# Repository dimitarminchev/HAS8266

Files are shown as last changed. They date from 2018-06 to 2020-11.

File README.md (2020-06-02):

# HAS & LAS 8266
Internet of Things (IoT) Home Automation System (HAS) and  Laboratory Automation System (LAS) based on ESP8266 with Energy Measurement Capabilities (HLW8012).

### Information
The basic hardware components are the ESP8266 micro-controller by Espressif and energy meter chip HLW8012 by HLW Technology. The Software works over the TCP/IP stack and uses the MQTT protocol to communicate between the devices. The minimum configuration of the platform includes one control device called Gateway and two or more manageable Host devices. The user friendly, simplified interface is web based. The platform has open software and hardware. 

### Authors
- Software: Dimitar Minchev, PhD of Informatics,  e-mail: <mitko@bfu.bg>
- Hardware: Atanas Dimitrov, PhD of Robots and manipulators, e-mail: <atanas@bfu.bg>

### Hardware and Software
The project is published as Open Source Hardware and Software.

Open Hardware
Open Source

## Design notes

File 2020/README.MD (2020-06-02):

# LAS8266
Internet of Things (IoT) Laboratory Automation System (LAS) based on ESP8266 with Energy Measurement Capabilities.

### Information
The basic hardware components are the ESP8266 micro-controller by Espressif and energy meter chip HLW8012 by HLW Technology. The Software works over the TCP/IP stack and uses the MQTT protocol to communicate between the devices. The minimum configuration of the LAS includes one control device called Gateway and two or more manageable Host devices. The user friendly, simplified interface is web based. The platform has open software and hardware. 

### Authors
- Software: Dimitar Minchev, PhD of Informatics,  e-mail: <mitko@bfu.bg>
- Hardware: Atanas Dimitrov, PhD of Robots and manipulators, e-mail: <atanas@bfu.bg>

### Youtube Demo
LAS8266 (https://youtu.be/b3r9DmQJEUk)

### Hardware


### Software
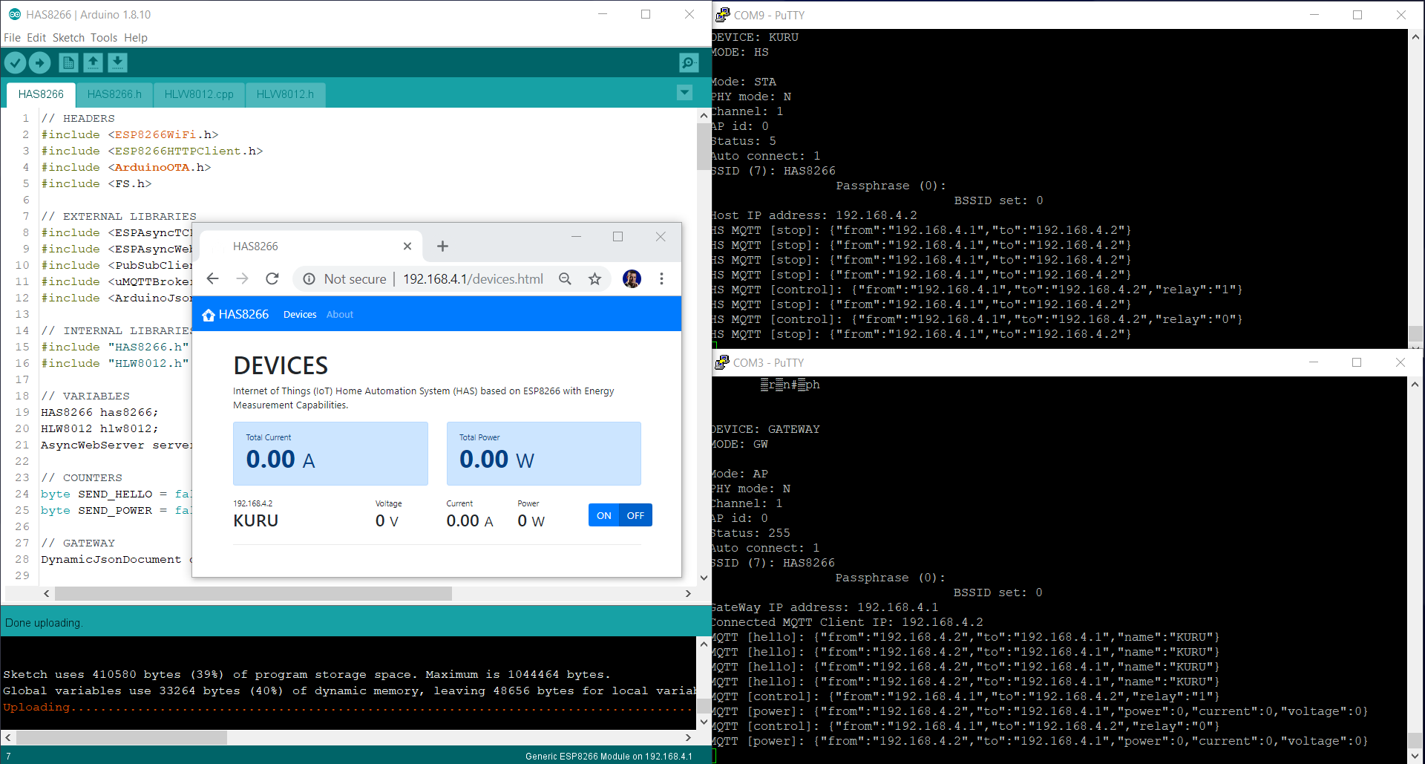
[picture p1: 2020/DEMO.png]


# Arduino 
### Libraries
- [ESPAsyncTCP](https://github.com/me-no-dev/ESPAsyncTCP)
- [ESPAsyncWebServer](https://github.com/me-no-dev/ESPAsyncWebServer)
- [PubSubClient](https://github.com/knolleary/pubsubclient)
- [uMQTTBroker](https://github.com/martin-ger/uMQTTBroker)
- [ArduinoJson](https://github.com/bblanchon/ArduinoJson)

### Settings
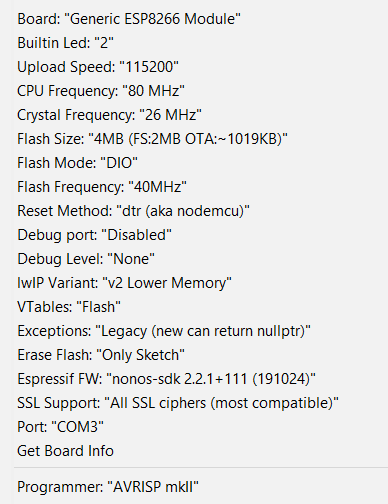
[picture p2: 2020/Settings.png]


The project is published as Open Source Hardware and Software.

Open Hardware
Open Source

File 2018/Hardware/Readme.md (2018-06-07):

# Hardware
In this directory you will find all gerber files needed for manufacturing the pcb of the HAS8266.

## HAS8266 Schematic
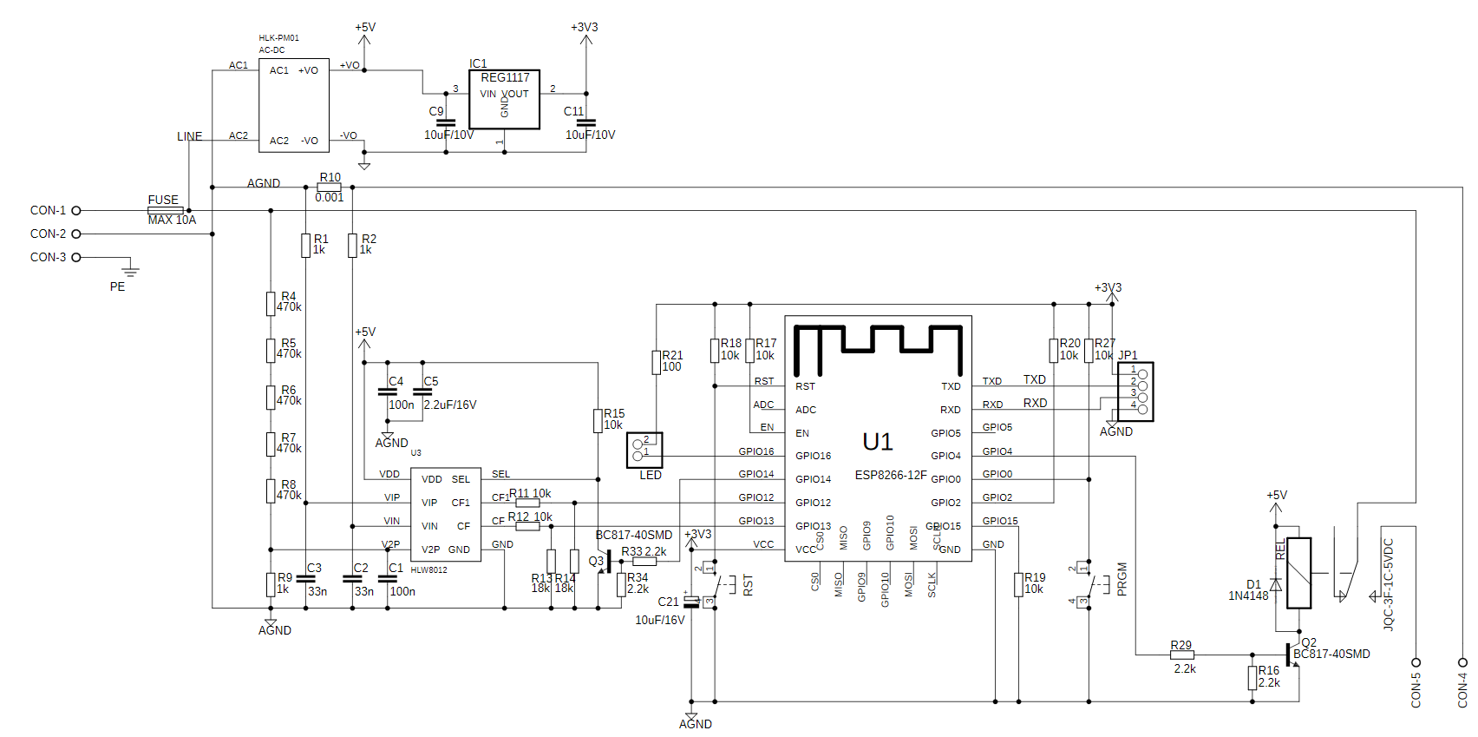
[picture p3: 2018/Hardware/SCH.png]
HAS8266 Schematic


## Gerber Files
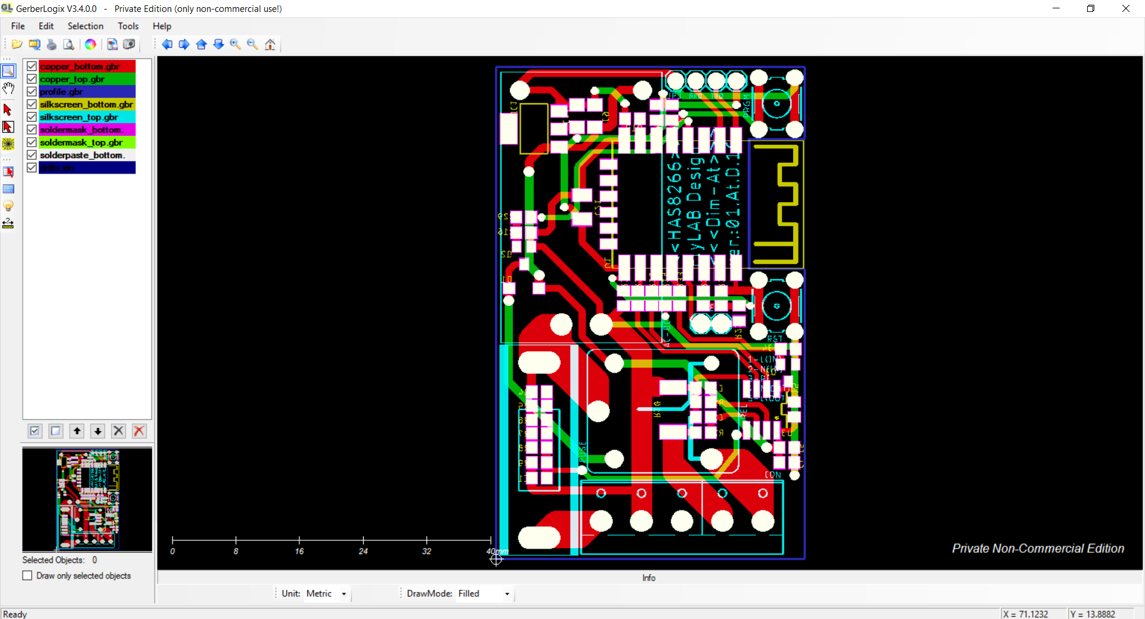
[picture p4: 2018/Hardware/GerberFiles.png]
Gerber Files


## Software
For design of PCB we used Autodesk Eagle
https://www.autodesk.com/products/eagle/free-download

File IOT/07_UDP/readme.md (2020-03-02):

# UDP
- ESP8266 Arduino Core UDP Demo
https://arduino-esp8266.readthedocs.io/en/latest/esp8266wifi/udp-examples.html

- UDP Demo GitHub Repository
https://github.com/esp8266/Arduino/blob/master/doc/esp8266wifi/udp-examples.rst

### Arduino
```
#include <ESP8266WiFi.h>
#include <WiFiUdp.h>

WiFiUDP Udp;

unsigned int localUdpPort = 5000; // local port to listen on
char incomingPacket[255]; // buffer for incoming packets
char replyPacket[] = "Thank You"; // a reply string to send back

void setup()
{
  Serial.begin(115200);
  Serial.println();

  // Access Point
  Serial.println("Access point waiting for client connection.");
  WiFi.mode(WIFI_AP);
  while (WiFi.softAPgetStationNum()== 0)
  {
    delay(1000);
    Serial.print(".");
  }
  
  // Udp
  Udp.begin(localUdpPort);
  Serial.println();
  Serial.printf("Now listening for packets at IP %s, UDP port %d\n", WiFi.softAPIP().toString().c_str(), localUdpPort);
}

void loop()
{
  delay(1000);
  int packetSize = Udp.parsePacket();
  if (packetSize)
  {
    // Receive incoming UDP packets
    Serial.printf("Received %d bytes from %s, port %d\n", packetSize, Udp.remoteIP().toString().c_str(), Udp.remotePort());
    int len = Udp.read(incomingPacket, 255);
    if (len > 0)
    {
      incomingPacket[len] = 0;
    }
    Serial.printf("UDP packet contents: %s\n", incomingPacket);

    // Send back a reply, to the IP address and port we got the packet from
    Udp.beginPacket(Udp.remoteIP(), Udp.remotePort());
    Udp.write(replyPacket);
    Udp.endPacket();
  }
}
```
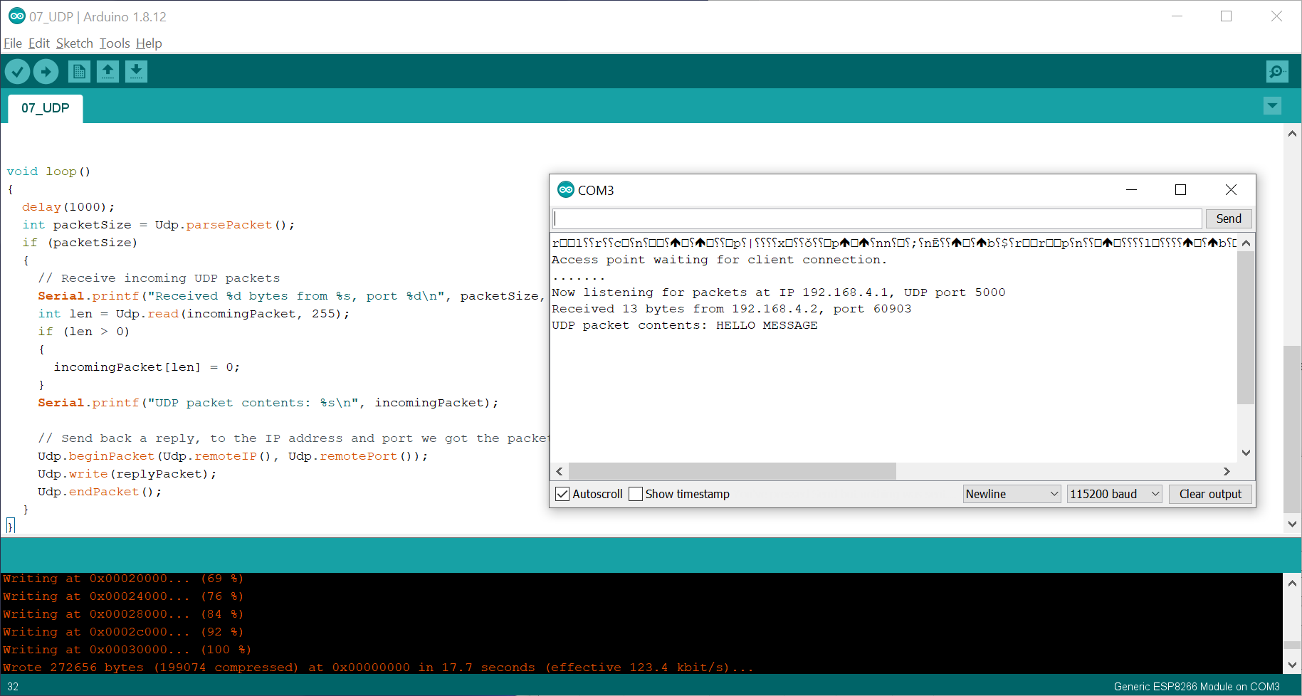
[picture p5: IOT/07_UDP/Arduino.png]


### Packet Sender
Packet Sender
https://packetsender.com/

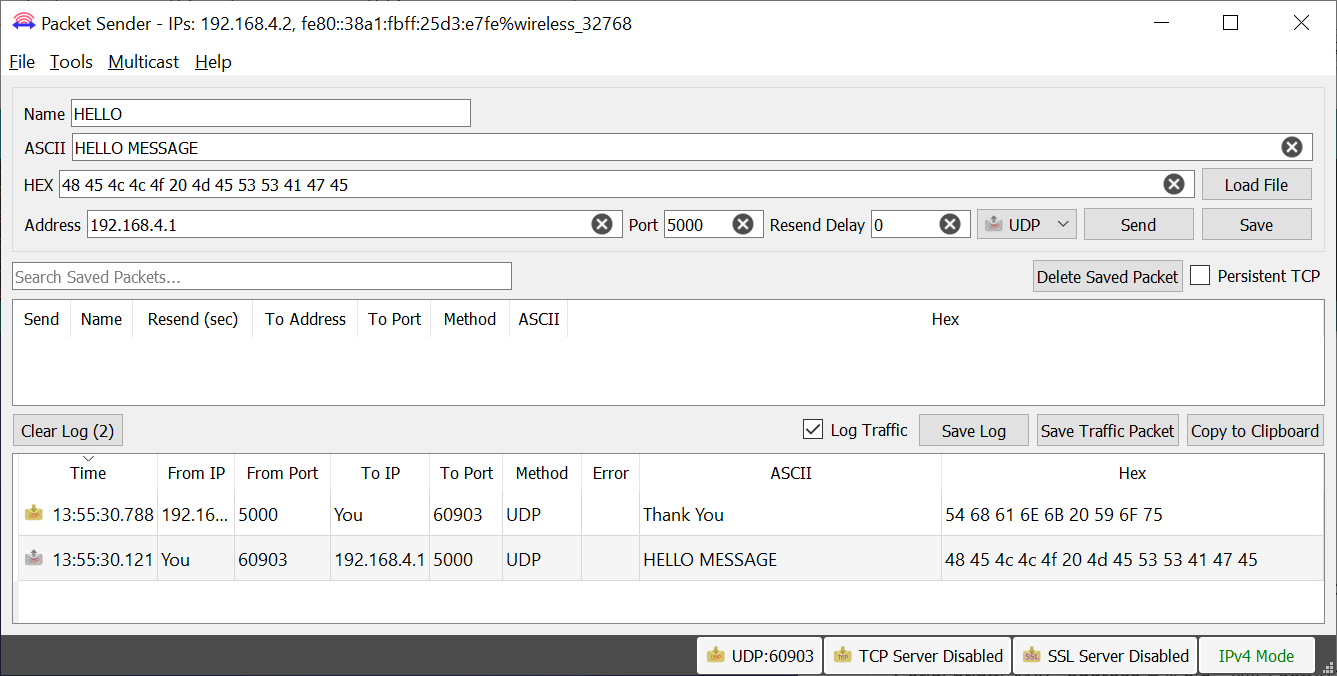
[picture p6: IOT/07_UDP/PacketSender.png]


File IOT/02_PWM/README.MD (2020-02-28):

# PWM
Arduino Pulse Width Modulation:
https://www.arduino.cc/en/Tutorial/PWM

```
// Initializing LED Pin
int led_pin = 16;

void setup() {
  //Declaring LED pin as output
  pinMode(led_pin, OUTPUT);
}

void loop() {
  // Fade In
  for(int i=0; i<255; i++){
    analogWrite(led_pin, i);
    delay(10);
  }
  // Fade Out
  for(int i=255; i>0; i--){
    analogWrite(led_pin, i);
    delay(10);
  }
}
```
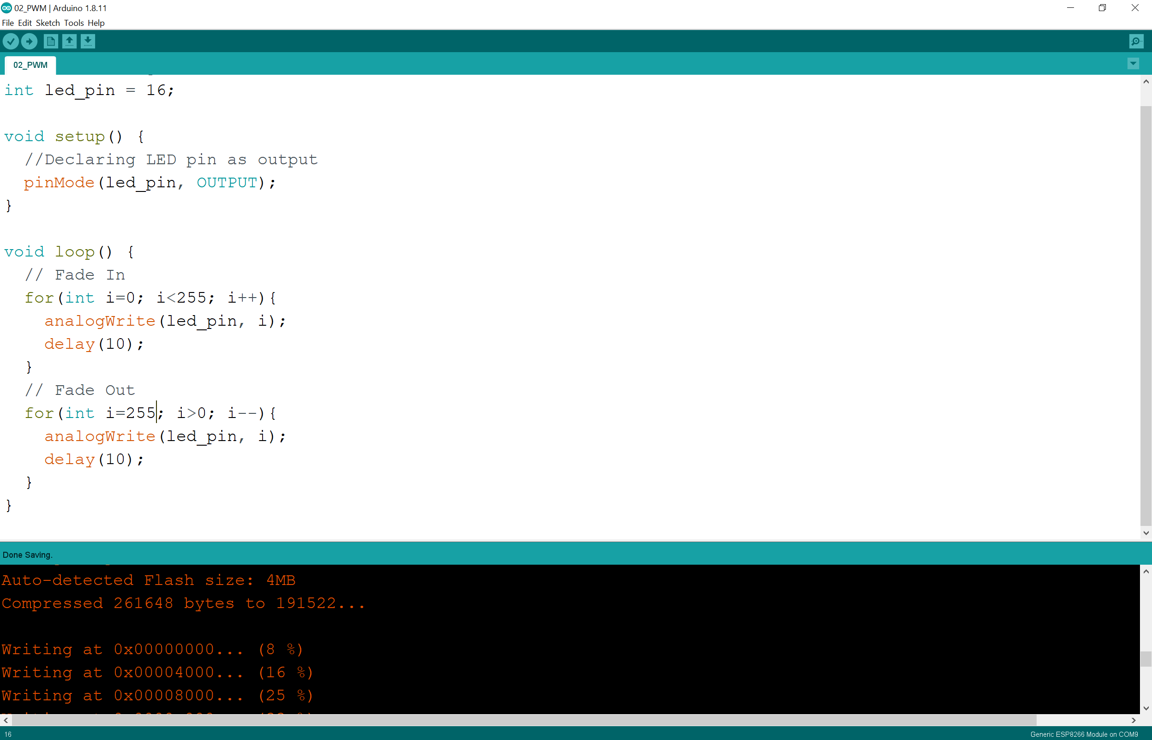
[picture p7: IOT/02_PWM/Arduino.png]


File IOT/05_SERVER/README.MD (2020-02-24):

# Access Point and Web Server
Start ESP8266 as a Access Point and then serve Client requests as a Web Server.

### Arduino
```
#include <ESP8266WiFi.h>
#include <ESP8266WebServer.h>
#include <FS.h>

// ESP8266 Web Server
ESP8266WebServer server(80);

// Setup
void setup(void) 
{
  // Access Point
  WiFi.mode(WIFI_AP);
  WiFi.softAP("ESP8266");
  // Server
  server.on("/", handleRequest);
  server.begin();
}

// Handle Client Request
void handleRequest() 
{
  // File System
  SPIFFS.begin();
  File file = SPIFFS.open("/index.html", "r");
  server.send(200, "text/html", file.readString());
  file.close();
  // server.send(200, "text/plain", "Hello world");
}

// Loop
void loop(void) 
{
  server.handleClient();
}
```
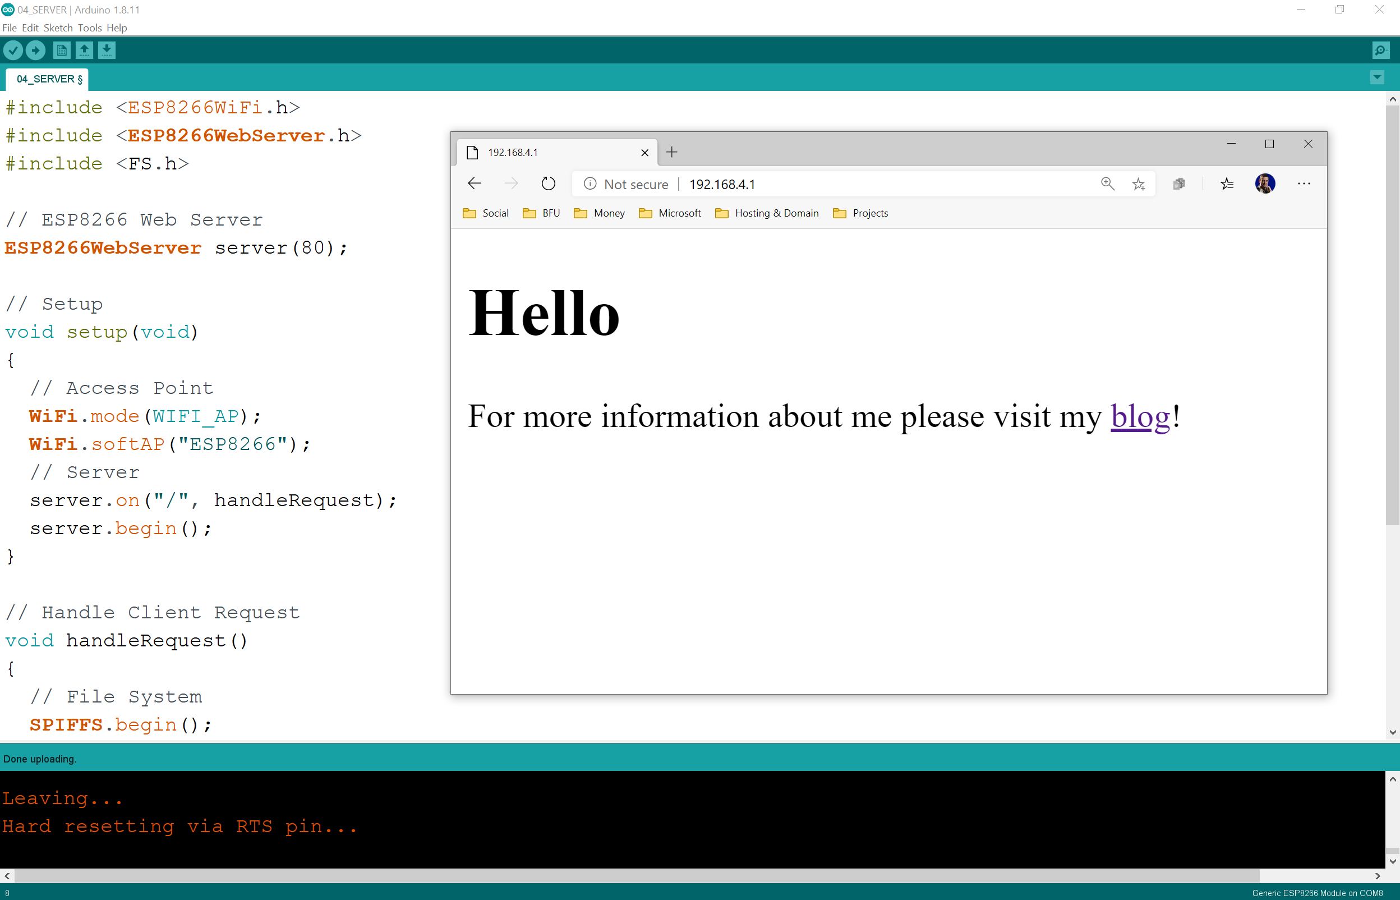
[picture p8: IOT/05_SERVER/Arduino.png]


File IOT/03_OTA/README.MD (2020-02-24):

# OTA

## Arduino
```
// Headers
#include <ESP8266WiFi.h>
#include <ESP8266mDNS.h>
#include <WiFiUdp.h>
#include <ArduinoOTA.h>

// WiFi Settings
#define SSID   "IBA_L@B"
#define PASS   ""

// Setup
void setup() 
{  
    // Connect to Wireless Network
    WiFi.mode(WIFI_STA);
    WiFi.begin(SSID,PASS);
    while (WiFi.status() != WL_CONNECTED) delay(1000);

    // OTA Updates 
    ArduinoOTA.setPort(8266); 
    ArduinoOTA.begin();
}

// Loop
void loop() 
{
    // Handle OTA Updates
    ArduinoOTA.handle();
}
```
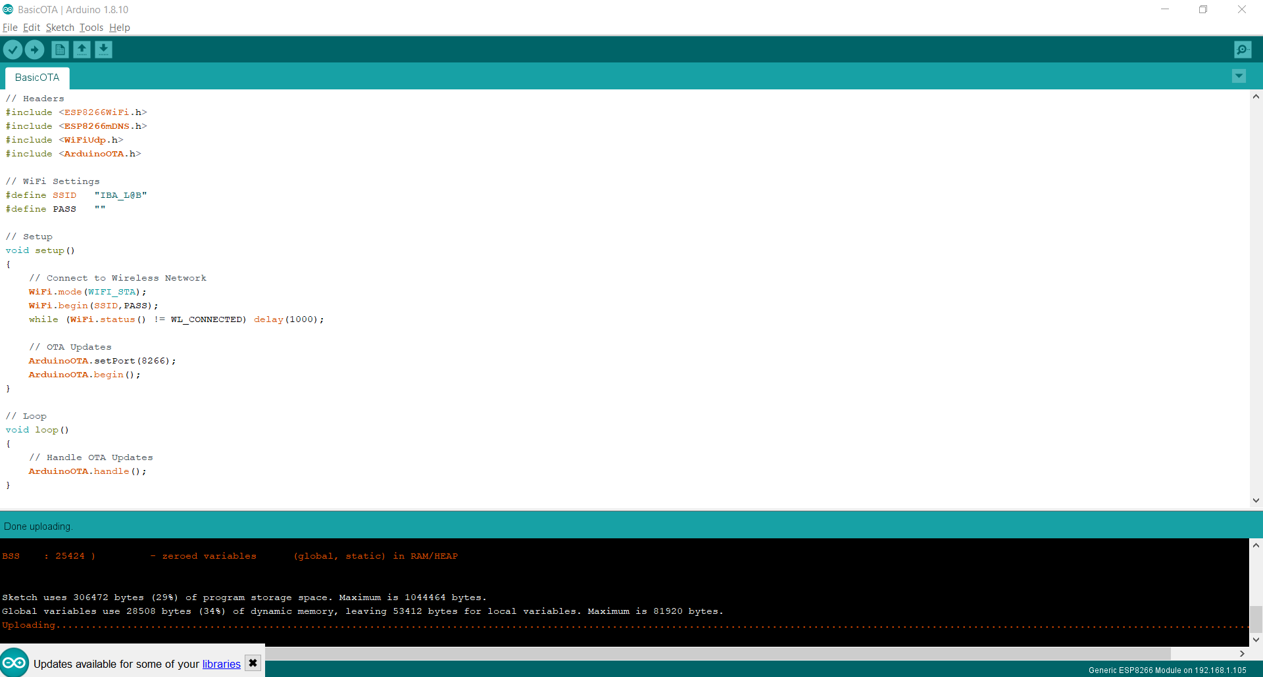
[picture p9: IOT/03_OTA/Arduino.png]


## PlatformIO
**platformio.ini**
```
; PlatformIO Project Configuration File

# ESP 8266 
[env:esp12e]
platform = espressif8266
board = esp12e
framework = arduino

# OTA 
upload_port = 192.168.1.105
upload_protocol = espota

# SERIAL 
; upload_port = COM3
; upload_speed = 115200
; monitor_speed = 115200
```
**main.cpp**
```
// Headers
#include <Arduino.h>
#include <ESP8266WiFi.h>
#include <WiFiUdp.h>
#include <ArduinoOTA.h>

// WiFi Settings
#define SSID   "IBA_L@B"
#define PASS   ""

// Setup
void setup() 
{  
    // Connect to Wireless Network
    WiFi.mode(WIFI_STA);
    WiFi.begin(SSID,PASS);
    while (WiFi.status() != WL_CONNECTED) delay(1000);

    // OTA Updates 
    ArduinoOTA.setPort(8266); 
    ArduinoOTA.begin();
}

// Loop
void loop() 
{
    // Handle OTA Updates
    ArduinoOTA.handle();
}
```
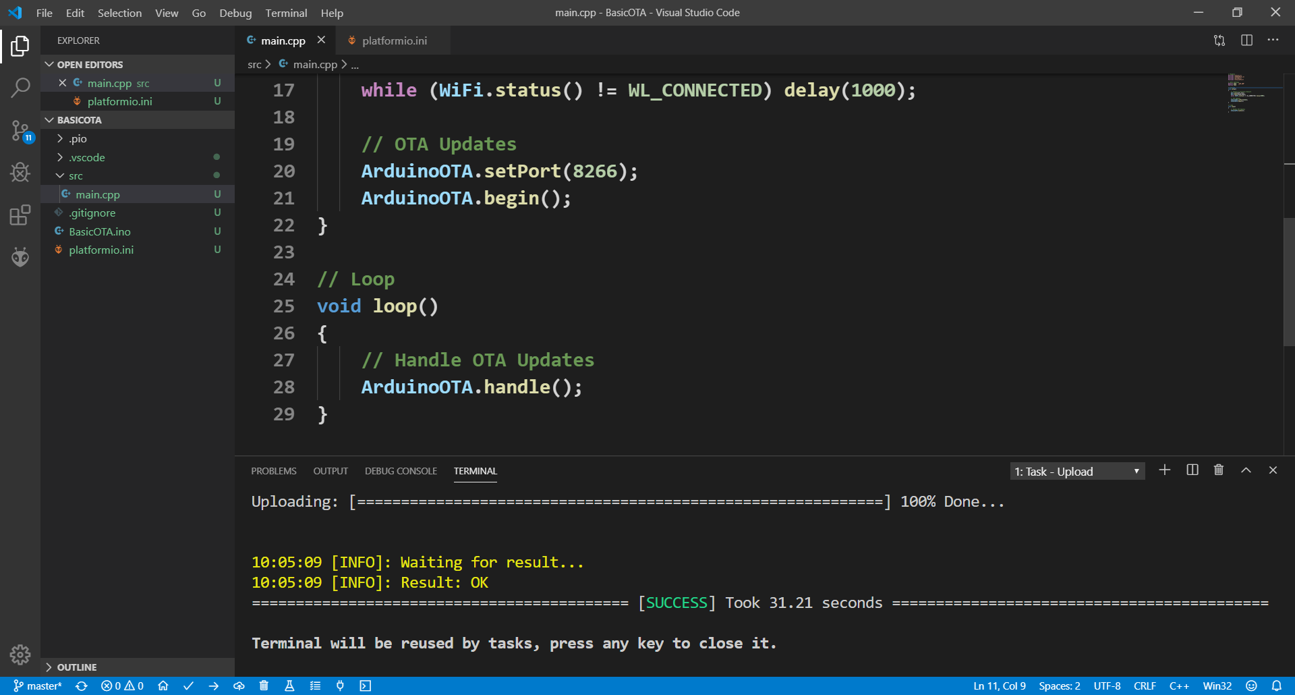
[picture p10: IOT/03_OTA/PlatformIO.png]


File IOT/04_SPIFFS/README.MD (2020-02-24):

# SPIFFS
- [SPIFFS](https://arduino-esp8266.readthedocs.io/en/latest/filesystem.html#flash-layout)
- [Arduino ESP8266 FileSystem Uploader](https://github.com/esp8266/arduino-esp8266fs-plugin/releases)
- [Python](https://go.microsoft.com/fwlink?linkID=2082640) 

### Arduino
```
// Headers
#include "FS.h"

// Setup
void setup() 
{
  Serial.begin(115200);
  
  // SPIFS
  SPIFFS.begin();
  Dir dir = SPIFFS.openDir("/");
  while (dir.next()) 
  {
    Serial.print(dir.fileName());
    if(dir.fileSize()) 
    {
        File f = dir.openFile("r");
        Serial.println(f.size());
    }
  }
}

// Loop
void loop() 
{
  // nope
}
```
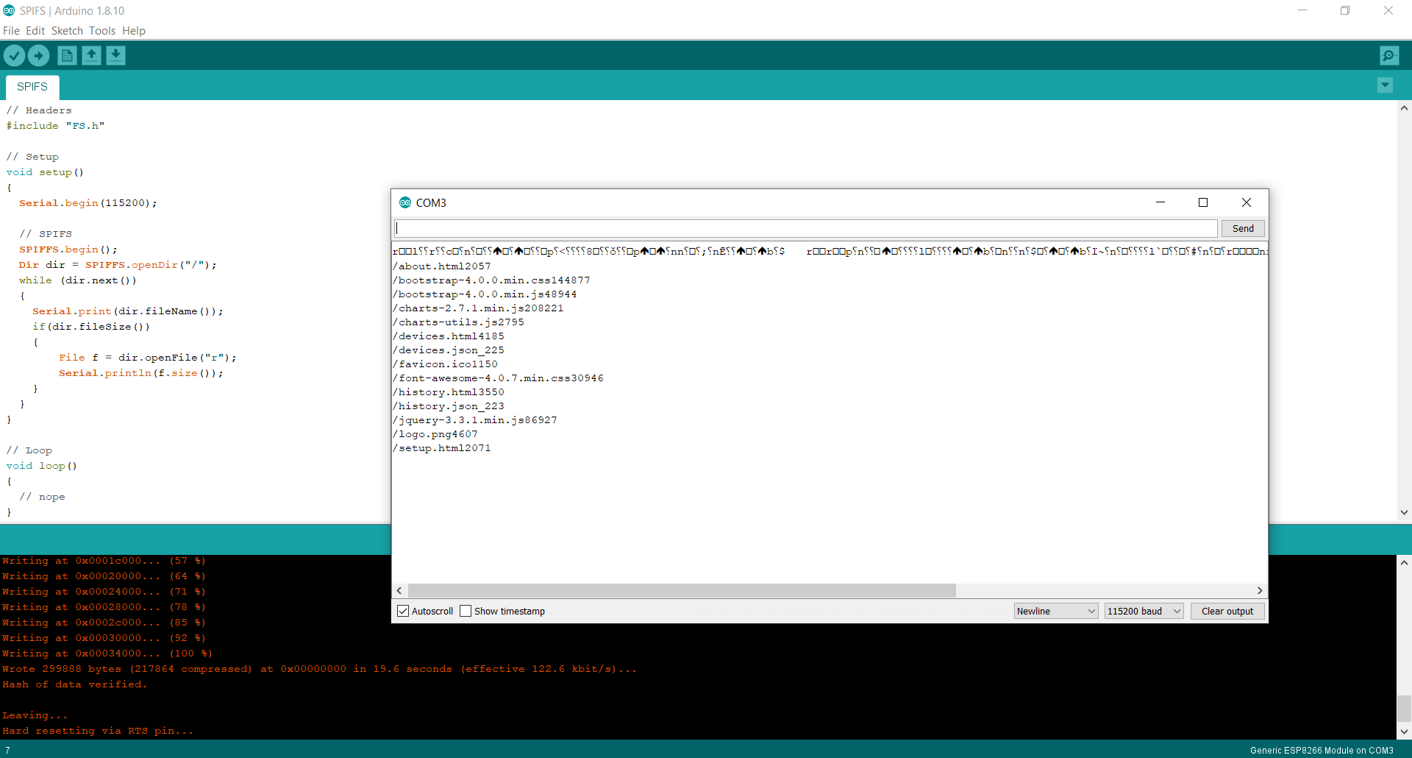
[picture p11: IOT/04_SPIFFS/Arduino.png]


## PlatformIO
**platformio.ini**
```
; PlatformIO Project Configuration File

# ESP 8266 
[env:esp12e]
platform = espressif8266
board = esp12e
framework = arduino

# SERIAL 
upload_port = COM3
upload_speed = 115200
monitor_speed = 115200
```
**main.cpp**
```
// Headers
#include <Arduino.h>
#include "FS.h"

// Setup
void setup() 
{
  Serial.begin(115200);
  delay(2000);
  
  // SPIFS
  SPIFFS.begin();
  Dir dir = SPIFFS.openDir("/");
  while (dir.next()) 
  {
    Serial.print(dir.fileName());
    if(dir.fileSize()) 
    {
        File f = dir.openFile("r");
        Serial.println(f.size());
    }
  }
}

// Loop
void loop() 
{
  // nope
}
```
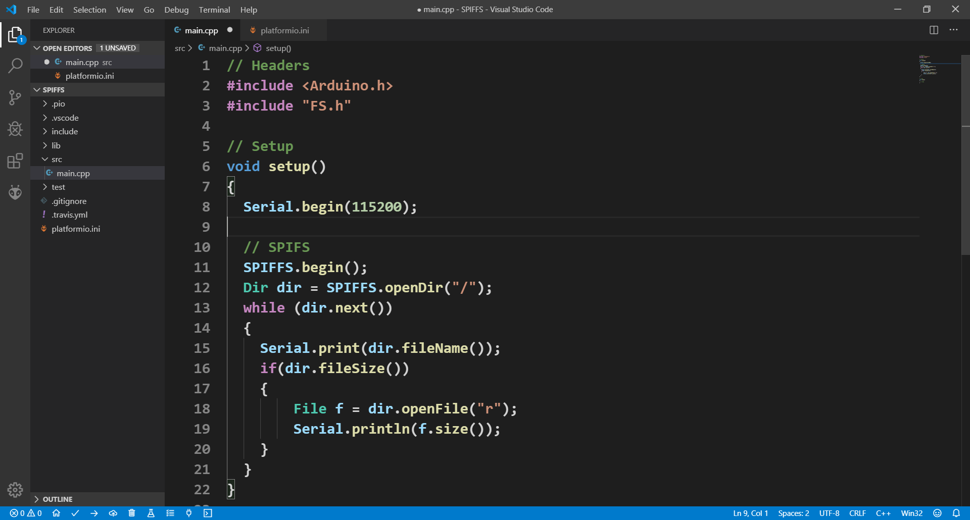
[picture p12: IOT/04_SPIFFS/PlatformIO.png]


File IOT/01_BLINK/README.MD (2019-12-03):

# BLINK

## INSTALL
Download and Install Arduino IDE
https://www.arduino.cc/en/Main/Software

## ESP8266
Install ESP8266 Add-on in Arduino IDE:

1. Arduino IDE
2. File > Preferences
3. Additional Boards Manager URLs:  http://arduino.esp8266.com/stable/package_esp8266com_index.json
4. Tools > Board > Boards Manager
5. Search and Install: **ESP8266**

## HARDWARE
Minimal Programming Schematics:
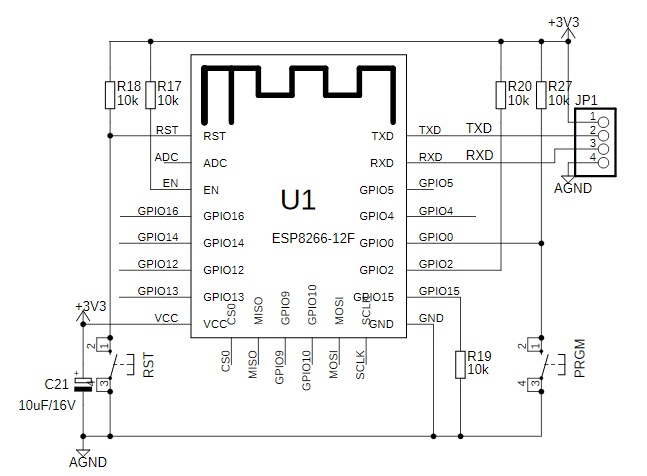
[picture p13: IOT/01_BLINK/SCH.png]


HAS8266 Device Ready to Program:
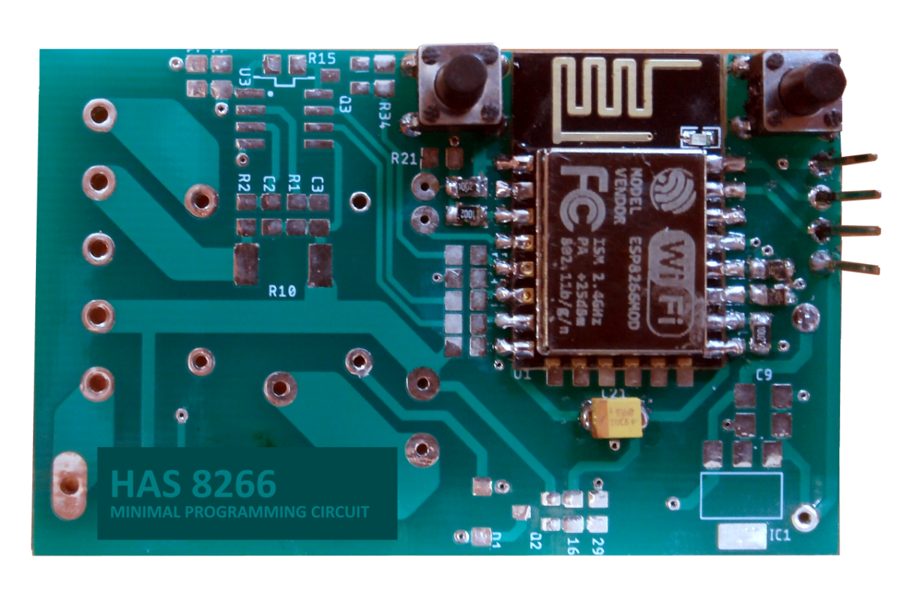
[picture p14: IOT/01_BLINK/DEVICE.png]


## SOFTWARE
```
// Initial Setup
void setup() 
{
  // Set pin as OUTPUT
  pinMode(LED_BUILTIN, OUTPUT); 
}

// Program Loop
void loop() 
{
  // Turn LED on and wait 1000 ms (1 sec)
  digitalWrite(LED_BUILTIN, HIGH); 
  delay(1000); 

  // Turn LED off and wait 1000 ms (1 sec)
  digitalWrite(LED_BUILTIN, LOW); 
  delay(1000); 
}
```
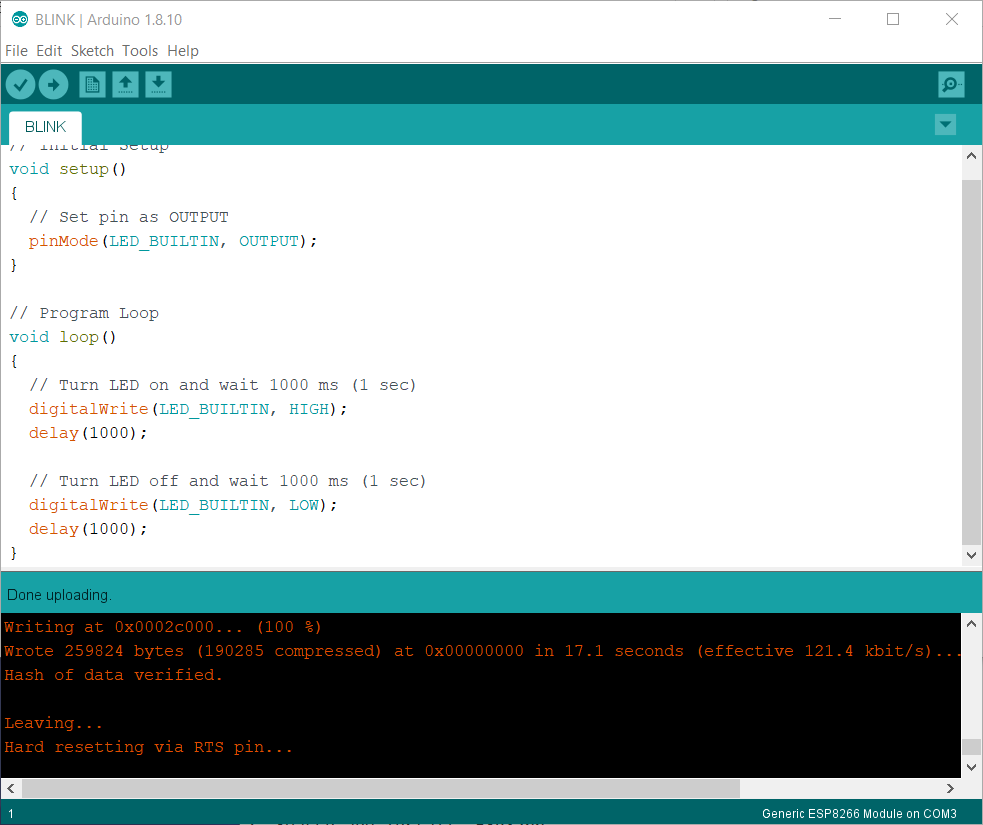
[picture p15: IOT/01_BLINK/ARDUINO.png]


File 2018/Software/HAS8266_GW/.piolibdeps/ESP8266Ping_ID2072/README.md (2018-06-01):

# ESP8266Ping
Let the ESP8266 ping a remote machine.

With this library an ESP8266 can ping a remote machine and know if it's reachable.
It provide some basic measurements on ping messages (avg response time).

## Usage

First, include the library in your sketch along with WiFi library:

```Arduino
#include <ESP8266WiFi.h>
#include <ESP8266Ping.h>
```

Next, simply call the `Ping.ping()` function

```Arduino
IPAddress ip (192, 168, 0, 1); // The remote ip to ping
bool ret = Ping.ping(ip);
```

`ret` will be true if the remote responded to pings, false if not reachable.
The library supports hostname too, just pass a string instead of the ip address:

```Arduino
bool ret = Ping.ping("www.google.com");
```

Additionally, the function accept a second integer parameter `count` that specify how many pings has to be sent:

```Arduino
bool ret = Ping.ping(ip_or_host, 10);
```

After `Ping.ping()` has been called, the average response time (in milliseconds) can be retrieved with

```Arduino
int avg_time_ms = Ping.averageTime();
```

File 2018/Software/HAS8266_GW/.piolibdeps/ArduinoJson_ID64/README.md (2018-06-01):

ArduinoJson

---

   

ArduinoJson is a C++ JSON library for Arduino and IoT (Internet Of Things).

## Features

* JSON decoding (comments are supported)
* JSON encoding (with optional indentation)
* Elegant API, easy to use
* Fixed memory allocation (zero malloc)
* No data duplication (zero copy)
* Portable (written in C++98, can be used in any C++ project)
* Self-contained (no external dependency)
* Small footprint
* Input and output streams
* [100% code coverage](https://coveralls.io/github/bblanchon/ArduinoJson)
* [Header-only library](https://en.wikipedia.org/wiki/Header-only)
* [MIT License](https://en.wikipedia.org/wiki/MIT_License)
* [Comprehensive documentation](https://arduinojson.org?utm_source=github&utm_medium=readme)

## Compatibility

ArduinoJson works on the following hardware:

*  Arduino boards: [Uno](https://www.arduino.cc/en/Main/ArduinoBoardUno), [Due](https://www.arduino.cc/en/Main/ArduinoBoardDue), [Mini](https://www.arduino.cc/en/Main/ArduinoBoardMini), [Micro](https://www.arduino.cc/en/Main/ArduinoBoardMicro), [Yun](https://www.arduino.cc/en/Main/ArduinoBoardYun)...
*  Espressif chips: [ESP8266](https://en.wikipedia.org/wiki/ESP8266), [ESP32](https://en.wikipedia.org/wiki/ESP32)
*  WeMos boards: [D1](https://wiki.wemos.cc/products:d1:d1), [D1 mini](https://wiki.wemos.cc/products:d1:d1_mini),  ...
*  RedBearLab boards: [BLE Nano](http://redbearlab.com/blenano/), [BLE Mini](http://redbearlab.com/blemini/), [WiFi Micro](https://redbear.cc/product/wifi/wifi-micro.html), [LOLIN32](https://wiki.wemos.cc/products:lolin32:lolin32)...
*  [Teensy](https://www.pjrc.com/teensy/) boards
*  Intel boards: Edison, Galileo...
*  Particle boards: [Photon](https://www.particle.io/products/hardware/photon-wifi-dev-kit), [Electron](https://www.particle.io/products/hardware/electron-cellular-dev-kit)...
*  Texas Instruments boards: [MSP430](http://www.ti.com/microcontrollers/msp430-ultra-low-power-mcus/overview/overview.html)...

ArduinoJson compiles with zero warning on the following compilers, IDEs, and platforms:

*  [Arduino IDE](https://www.arduino.cc/en/Main/Software)
*  [PlatformIO](http://platformio.org/)
*  [Energia](http://energia.nu/)
*  [Visual Micro](http://www.visualmicro.com/)
*  [Atmel Studio](http://www.atmel.com/microsite/atmel-studio/)
*  [IAR Embedded Workbench](https://www.iar.com/iar-embedded-workbench/)
*  [Atollic TrueSTUDIO](https://atollic.com/truestudio/)
*  [Keil uVision](http://www.keil.com/)
*  [MPLAB X IDE](http://www.microchip.com/mplab/mplab-x-ide)
*  [GCC](https://gcc.gnu.org/)
*  [Clang](https://clang.llvm.org/)
*  [Visual Studio](https://www.visualstudio.com/)

## Quickstart

### Deserialization

Here is a program that parses a JSON document with ArduinoJson.

```c++
char json[] = "{\"sensor\":\"gps\",\"time\":1351824120,\"data\":[48.756080,2.302038]}";

StaticJsonBuffer<200> jsonBuffer;

JsonObject& root = jsonBuffer.parseObject(json);

const char* sensor = root["sensor"];
long time          = root["time"];
double latitude    = root["data"][0];
double longitude   = root["data"][1];
```

See the [tutorial on arduinojson.org](https://arduinojson.org/doc/decoding/?utm_source=github&utm_medium=readme)

### Serialization

Here is a program that generates a JSON document with ArduinoJson:

```c++
StaticJsonBuffer<200> jsonBuffer;

JsonObject& root = jsonBuffer.createObject();
root["sensor"] = "gps";
root["time"] = 1351824120;

JsonArray& data = root.createNestedArray("data");
data.add(48.756080);
data.add(2.302038);

root.printTo(Serial);
// This prints:
// {"sensor":"gps","time":1351824120,"data":[48.756080,2.302038]}
```

See the [tutorial on arduinojson.org](https://arduinojson.org/doc/encoding/?utm_source=github&utm_medium=readme)

## Documentation

The documentation is available on [arduinojson.org](https://arduinojson.org/?utm_source=github&utm_medium=readme), here are some shortcuts:

* The [Examples](https://arduinojson.org/example/?utm_source=github&utm_medium=readme) show how to use the library in various situations.
* The [API Reference](https://arduinojson.org/api/?utm_source=github&utm_medium=readme) contains the description of each class and function.
* The [FAQ](https://arduinojson.org/faq/?utm_source=github&utm_medium=readme) has the answer to virtually every question.
* The [ArduinoJson Assistant](https://arduinojson.org/assistant/?utm_source=github&utm_medium=readme) writes programs for you!

---

Do you like this library? Please [star this project on GitHub](https://github.com/bblanchon/ArduinoJson/stargazers)!

What? You don't like it but you *love* it?
We don't take donations anymore, but [we sell a book](https://arduinojson.org/book/?utm_source=github&utm_medium=readme), so you can help and learn at the same time!

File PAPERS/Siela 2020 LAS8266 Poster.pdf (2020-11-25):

Online Conference
3 - 6 June 2020, Bulgaria

# Laboratory Automation System Using IOT Devices

### Dimitar MINCHEV*, Atanas DIMITROV**

* Burgas Free University, Faculty of Computer Science and Engineering, Burgas, Bulgaria; ** IBA Bulgaria, 9 “Bulair” Str., Burgas, Bulgaria

# I. Introduction

# III. Software

II. Architecture | IV. Hardware

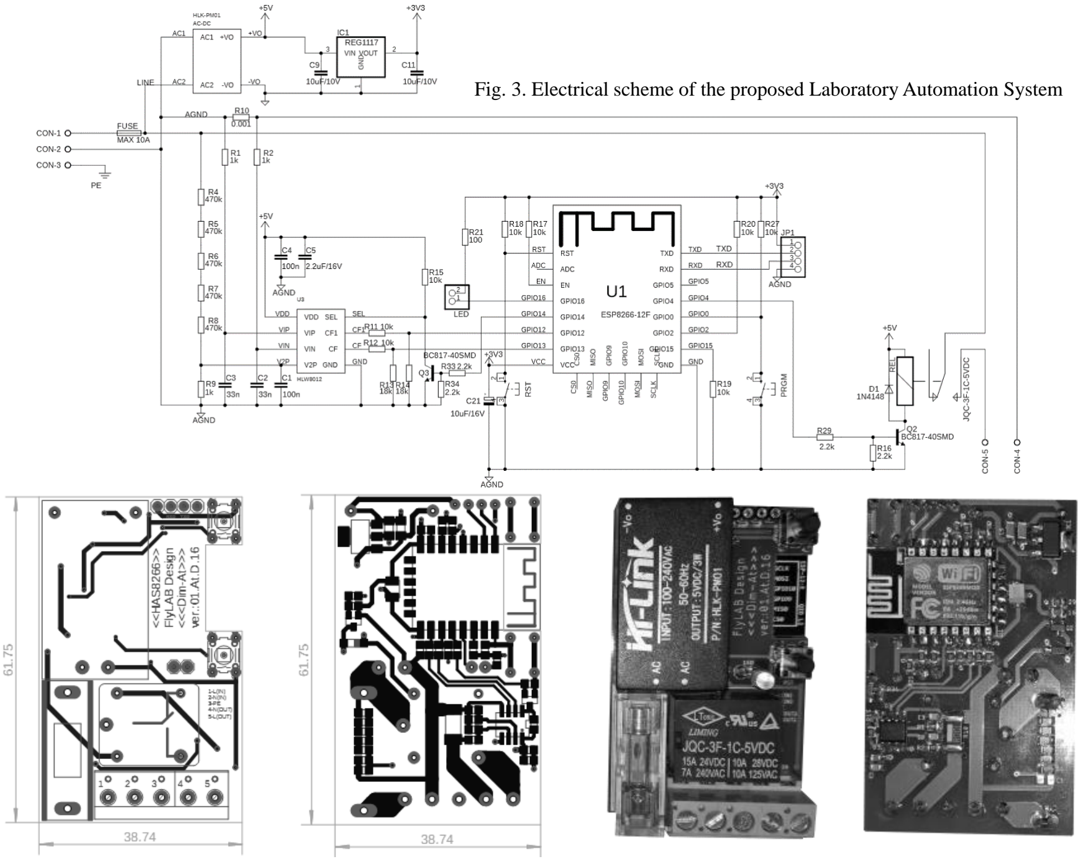
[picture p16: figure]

# V. Conclusion

This paper describes a Laboratory Automation System using IoT devices. The main hardware modules consist ESP8266 micro-controller by Espressif and energy meter HLW8012 by HLW Technology. Communication between the IoT devices uses IEEE 802.11g WiFi network, TCP/IP stack and MQTT protocol. The minimum configuration of the project includes one control device called Gateway and two or more manageable Host devices. The devices can be controlled remotely by user friendly, simplified web-based interface. The project is open software and hardware.

Internet of Things (IoT) is becoming more and more a part of our lives on a daily basis. IoT devices are primarily used to control, monitor, and manage the technology that we use every day. This means that the devices are typically designed to be easily installed and managed by the costumer. Industry analysts estimate the number of connected devices to be approx. 50 billion by the end of the 2020 year. This paper describes the implementation of Laboratory Automation System (LAS) using IoT Devices with energy measurement capabilities.

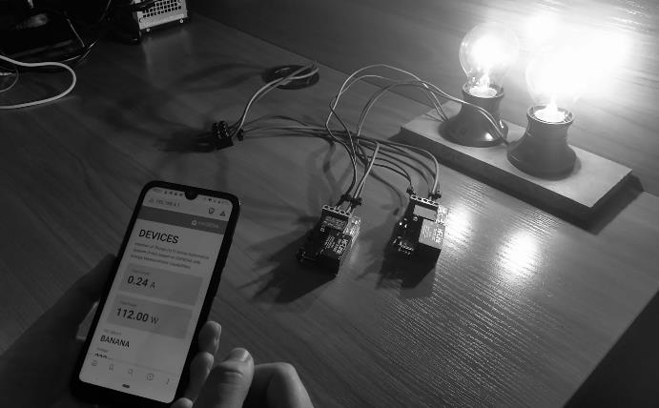
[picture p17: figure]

The source code of the project is written in C/C++ using Arduino IDE [4]. During the development of the firmware, additional external libraries were used as follows:
- ESPAsyncTCP [5] - Asynchronous TCP library, aimed at enabling trouble-free, multiconnection network environment for Espressif's ESP8266 MCUs.
- ESPAsyncWebServer [6] - Arduino compatible Asynchronous HTTP and WebSocket Server for ESP8266.
- PubSubClient [7] - This library provides a client for doing simple publish/subscribe messaging with a server that supports MQTT.
- uMQTTBroker [8] - Arduino compatible MQTT Broker library for Espressif's ESP8266 MCUs.
- ArduinoJson [9] - JSON message protocol library implementation in C++ for Arduino and IoT.
- | HLW8012 | [10] | – | Arduino | energy
measurement library by Xose Perez.
The full source code of the project is available as open software in GitHub Repository and can be freely downloaded on the Internet at address: https://github.com/dimitarminchev/HAS8266 Testing the project software in laboratory-controlled environment on mobile device and laptop is shown on Fig.2.

The proposed system architecture model is modular and consists of multiple end devices, called Hosts. The Hosts are capable of incorporating a variety of laboratory electrical appliances. Each of these end-devices has a wireless network interface which is connected to the single control device and called Gateway. The Gateway controls the operation of all Hosts. It establishes a communication channel between costumer and Hosts, thereby providing their remote control and management.
The Message Queue Telemetry Transport (MQTT) [1] communication protocol is used to transmit data between Hosts and Gateway devices. The choice of this communication protocol is due to its advantages. It is lightweight, open to the public, as described in the OASIS [2] specification, standardized by ISO/IEC PRF 20922 [3] and it working over the Transmission Control Protocol/ Internet Protocol (TCP/IP).
When is powered, a single Host introduces itself to the Gateway with continuous “Hello” message. This identification message contains the name of the Host. After receiving the message, the Gateway is responding back to the “Hello” message with a new “Stop” message. In this way, the Gateway confirms the Host that it is successfully connected to the network, manageable by Gateway and adds its IP address to his routing table.
When the Gateway receive user command to turn-on a specific device, it send “Control” message to the device IP address from the routing table to power on the desired Host. Receiving “Control” message, the Host periodically respond with “Power” message until Gateway send “Stop” message. The “Power” message consists of information for power consumption, measured by HLW8012, and contains three fields: voltage of the power grid, consumed current and active power from managed device.
When the Gateway receive user command to turn-off a specific device, it send “Control” message to the device IP address from the routing table to power off the desired Host.
The UML sequence diagram of the MQTT communication protocol between Gateway and Host device is shown on Fig. 1.

This paper describes the implementation of a Laboratory Automation System (LAS) using Internet of Thing (IoT) devices. The main hardware modules consist ESP8266 micro-controller by Espressif and energy meter HLW8012 by HLW Technology. Communication between the IoT devices uses IEEE 802.11g WiFi network, TCP/IP stack and MQTT protocol. The minimum configuration of the project includes one control device called Gateway and two or more manageable Host devices. The devices can be controlled remotely by user friendly, simplified web-based interface. The project is open software and hardware.

REFERENCES
[1] Message Queue Telemetry Transport (MQTT), http://www.mqtt.org
[2] OASIS Standard Incorporating Approved Errata 01, MQTT Version 3.1.1 Plus Errata 01, http://docs.oasis-open.org/mqtt/mqtt/v3.1.1/mqtt-v3.1.1.html
[3] ISO/IEC 20922:2016, Information technology, Message Queuing Telemetry Transport (MQTT) v3.1.1, https://www.iso.org/standard/69466.html
[4] Arduino IDE, https://www.arduino.cc/en/Main/Software
[5] ESPAsyncTCP, https://github.com/me-no-dev/ESPAsyncTCP
[6] ESPAsyncWebServer, https://github.com/me-no-dev/ESPAsyncWebServer
[7] PubSubClient, https://github.com/knolleary/pubsubclient
[8] uMQTTBroker, https://github.com/martin-ger/uMQTTBroker
[9] ArduinoJson, https://github.com/bblanchon/ArduinoJson
[10] X. Perez, HLW8012, https://bitbucket.org/xoseperez/hlw8012
[11] ESP8266EX, Espressif System, https://www.espressif.com/sites/default/files/documentation/0a-esp8266ex_datasheet_en.pdf
[12] HLW8012, Hiliwi Technologies, www.hiliwi.com/products_detail/&productId=36.html

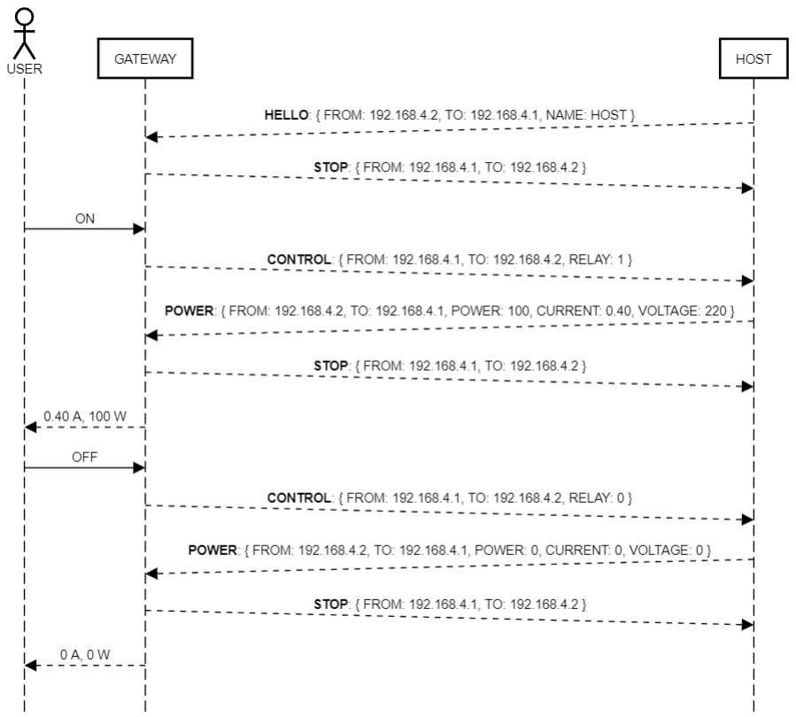
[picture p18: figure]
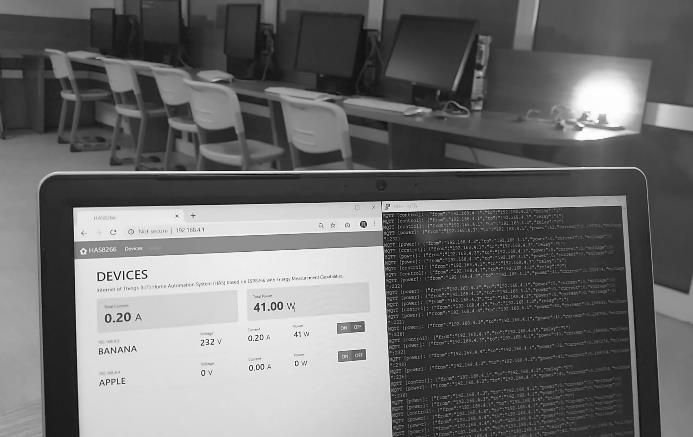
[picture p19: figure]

Fig. 2. Testing the project software in laboratory-controlled environment | Fig. 1. UML Sequence Diagram of the MQTT Communication protocol

Fig. 4 and 5. Graphical originals and PCB of the proposed Laboratory Automation System

Fig. 3. Electrical scheme of the proposed Laboratory Automation System

The ESP8266 chip integrates an ultra-low power 32-bit MCU architecture. The core of the processor can work with clock speed of 80MHz or 160MHz. The module supports RTOS, IEEE802.11 b/g/n standard and complete TCP/IP stack, which is make it ideal for adding to an existing network device or building a separate network controller. HLW8012 can measure RMS values of current, voltage, and active power with an internal clock and a PWM interface. To operate, HLW8012 chip needs 5V DC voltage. It generates 50% duty square waves with frequency that depends on the magnitude of the measured parameter (power, current, or voltage).

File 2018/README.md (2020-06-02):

# HAS8266
Internet of Things (IoT) Home Automation System (HAS) based on ESP8266 with Energy Measurement Capabilities (HLW8012).

### Information
The basic hardware components are the ESP8266 micro-controller by Espressif and energy meter chip HLW8012 by HLW Technology. The Software works over the TCP/IP stack and uses the MQTT protocol to communicate between the devices. The minimum configuration of the HAS includes one control device called Gateway and two or more manageable Host devices. The user friendly, simplified interface is web based. The platform has open software and hardware. 

### Authors
- Software: Dimitar Minchev, PhD of Informatics,  e-mail: <mitko@bfu.bg>
- Hardware: Atanas Dimitrov, PhD of Robots and manipulators, e-mail: <atanas@bfu.bg>

### Youtube demo
HAS8266 (https://youtu.be/SIjooKtCkP0)

### Hardware and Software
- [ESP8266EX, Espressif System](http://www.espressif.com/sites/default/files/documentation/0aesp8266ex_datasheet_en.pdf)
- [HLW8012, Hiliwi Technologies](http://www.hiliwi.com/products_detail/&productId=36.html)
- [Microsoft Visual Studio Code](http://code.visualstudio.com/download)
- [PlatformIO IDE for VSCode](http://platformio.org/platformio-ide)

The project is published as Open Source Hardware and Software.

Open Hardware
Open Source

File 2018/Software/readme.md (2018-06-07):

# Software
This folder contains the software part of the HAS8266 project.

## Architecture
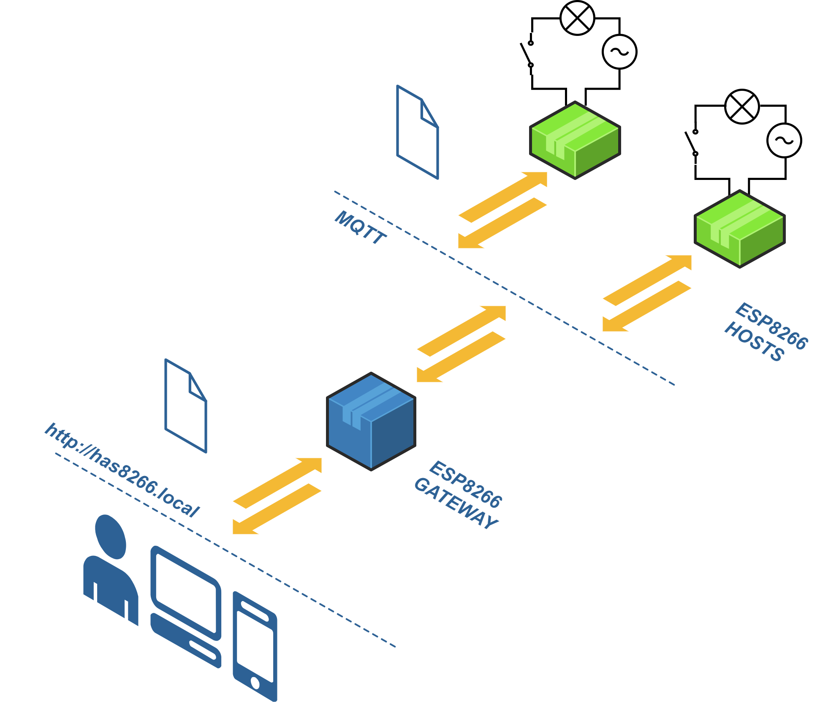
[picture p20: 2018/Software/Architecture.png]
Architecture


## GateWay
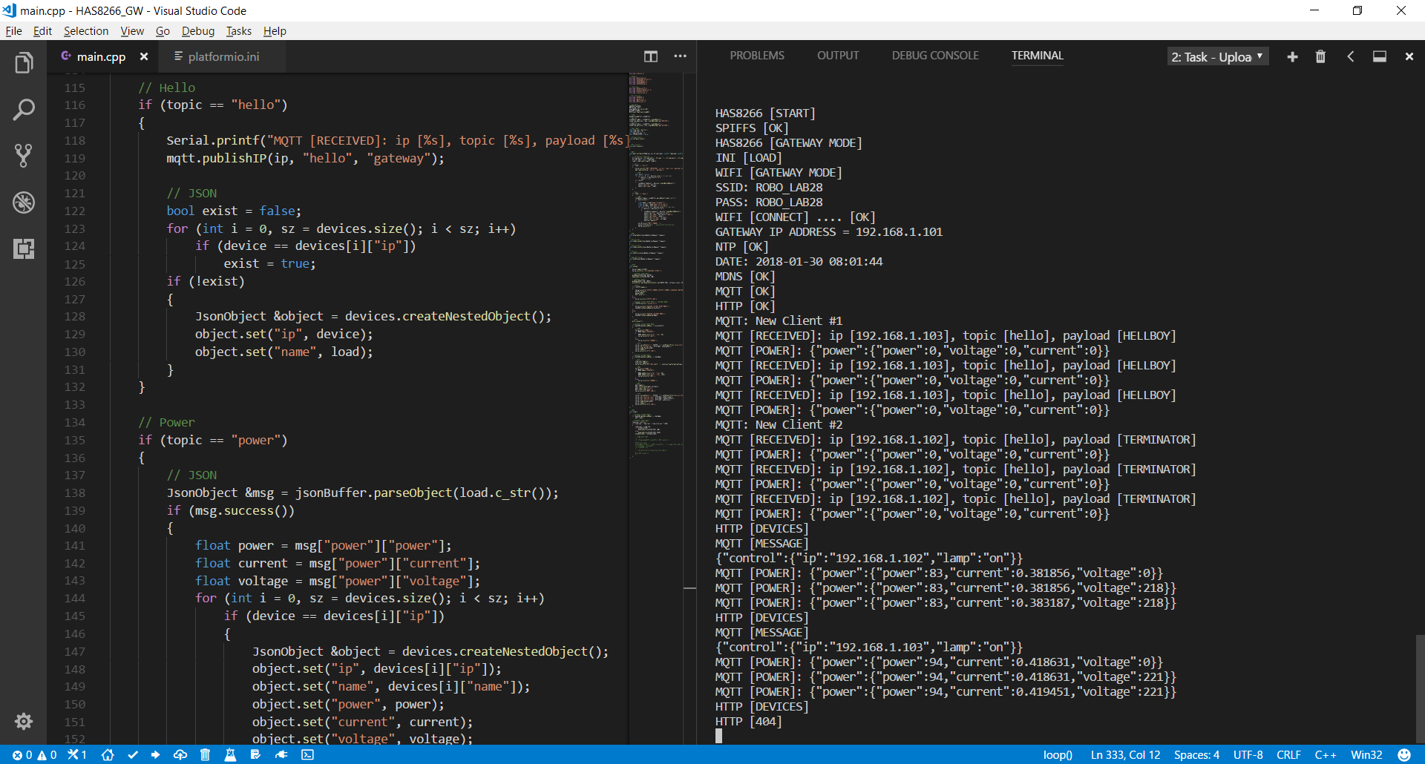
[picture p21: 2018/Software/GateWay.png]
GateWay


## Host
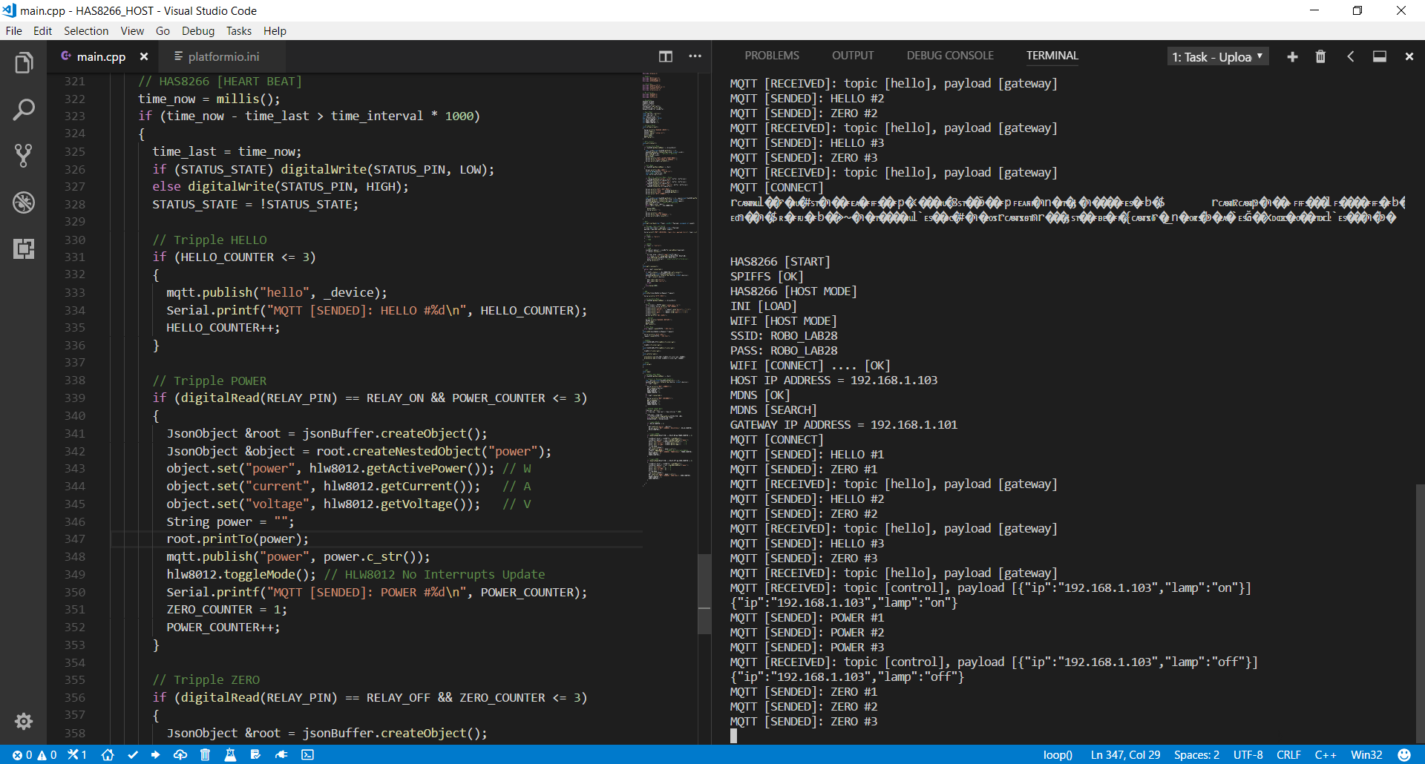
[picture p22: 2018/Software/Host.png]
Host


## Cominication
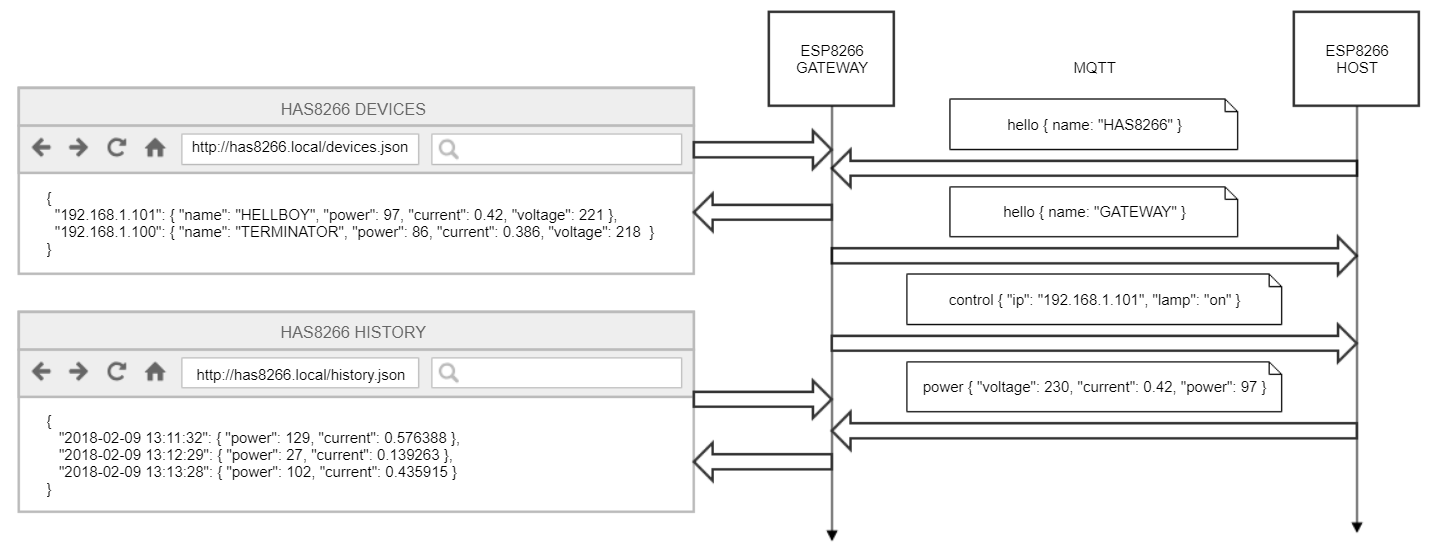
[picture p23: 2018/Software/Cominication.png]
Cominication


## Web
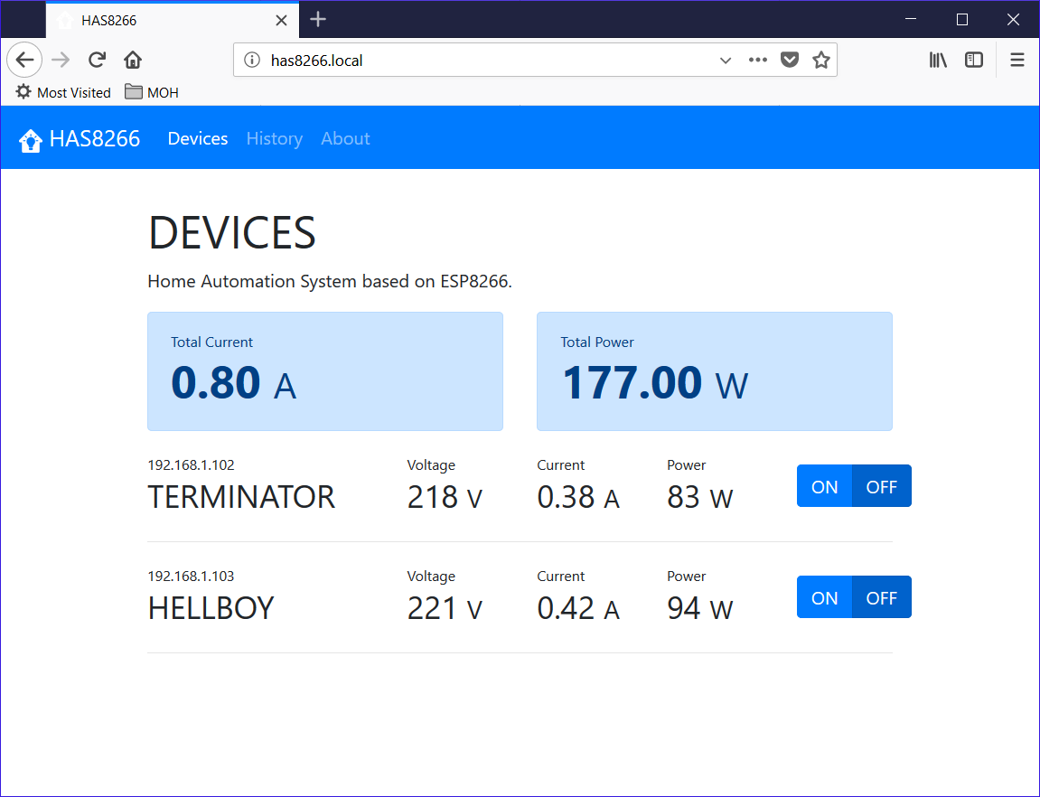
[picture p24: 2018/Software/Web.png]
Web


## Requirements
- [Microsoft Visual Studio Code](http://code.visualstudio.com/download)
- [PlatformIO IDE for VSCode](http://platformio.org/platformio-ide)

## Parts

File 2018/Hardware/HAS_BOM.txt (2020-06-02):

Partlist exported from C:/Users/dimit/Documents/eagle/HAS_MAN/HAS/HAS.sch at 02/07/18 13:04

Qty Value          Device         Package        Parts                                  Description                                       
2                  10-XX          B3F-10XX       PRGM, RST                              OMRON SWITCH                                      
1                  PINHD-1X2      1X02           LED                                    PIN HEADER                                        
1                  PINHD-1X4      1X04           JP1                                    PIN HEADER                                        
1                  W237-05P       W237-5P        CON                                    WAGO SREW CLAMP                                   
1   0.001          R-EU_R2512     R2512          R10                                    RESISTOR, European symbol                         
1   100            R-EU_R0805     R0805          R21                                    RESISTOR, European symbol                         
2   100n           C-EUC0805      C0805          C1, C4                                 CAPACITOR, European symbol                        
8   10k            R-EU_R0805     R0805          R11, R12, R15, R17, R18, R19, R20, R27 RESISTOR, European symbol                         
2   10uF/10V       C-EUC1206      C1206          C9, C11                                CAPACITOR, European symbol                        
1   10uF/16V       CPOL-EUSMCB    SMC_B          C21                                    POLARIZED CAPACITOR, European symbol              
2   18k            R-EU_R0805     R0805          R13, R14                               RESISTOR, European symbol                         
1   1N4148         DIODE-SOD123   SOD123         D1                                     DIODE                                             
3   1k             R-EU_R0805     R0805          R1, R2, R9                             RESISTOR, European symbol                         
4   2.2k           R-EU_R0805     R0805          R16, R29, R33, R34                     RESISTOR, European symbol                         
1   2.2uF/16V      C-EUC0805      C0805          C5                                     CAPACITOR, European symbol                        
2   33n            C-EUC0805      C0805          C2, C3                                 CAPACITOR, European symbol                        
5   470k           R-EU_R0805     R0805          R4, R5, R6, R7, R8                     RESISTOR, European symbol                         
2   BC817-40SMD    BC817-40SMD    SOT23-BEC      Q2, Q3                                 NPN Transistor                                    
1   ESP8266-12F    ESP8266-12F    ESP8266-12F    U1                                                                                       
1   HLK-PM01       HLK-PM01       HLK-PM01       AC-DC                                                                                    
1   HLW8012        HLW8012        HLW8012        U3                                                                                       
1   JQC-3F-1C-5VDC JQC-3F-1C-5VDC JQC-3F-1C-5VDC REL                                                                                      
1   MAX 10A        FUSESH22       SH22           FUSE                                   Fuse                                              
1   REG1117        REG1117        SOT223         IC1                                    800mA and 1A Low Dropout (LDO) Positive Regulator

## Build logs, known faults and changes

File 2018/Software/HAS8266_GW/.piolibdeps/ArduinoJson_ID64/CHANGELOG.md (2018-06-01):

ArduinoJson: change log
=======================

v5.13.0
-------

* Changed the rules of string duplication (issue #658)
* `RawJson()` accepts any kind of string and obeys to the same rules for duplication
* Changed the return type of `strdup()` to `const char*` to prevent double duplication
* Marked `strdup()` as deprecated

> ### New rules for string duplication
>
> | type                       | duplication |
> |:---------------------------|:------------|
> | const char*                | no          |
> | char*                      | ~~no~~ yes  |
> | String                     | yes         |
> | std::string                | yes         |
> | const __FlashStringHelper* | yes         |
>
> These new rules make `JsonBuffer::strdup()` useless.

v5.12.0
-------

* Added `JsonVariant::operator|` to return a default value (see below)
* Added a clear error message when compiled as C instead of C++ (issue #629)
* Added detection of MPLAB XC compiler (issue #629)
* Added detection of Keil ARM Compiler (issue #629)
* Added an example that shows how to save and load a configuration file
* Reworked all other examples

> ### How to use the new feature?
>
> If you have a block like this:
>
> ```c++
> const char* ssid = root["ssid"];
> if (!ssid)
>   ssid = "default ssid";
> ```
>
> You can simplify like that:
>
> ```c++
> const char* ssid = root["ssid"] | "default ssid";
> ```

v5.11.2
-------

* Fixed `DynamicJsonBuffer::clear()` not resetting allocation size (issue #561)
* Fixed incorrect rounding for float values (issue #588)

v5.11.1
-------

* Removed dependency on `PGM_P` as Particle 0.6.2 doesn't define it (issue #546)
* Fixed warning "dereferencing type-punned pointer will break strict-aliasing rules [-Wstrict-aliasing]"
* Fixed warning "floating constant exceeds range of 'float' [-Woverflow]" (issue #544)
* Fixed warning "this statement may fall through" [-Wimplicit-fallthrough=] (issue #539)
* Removed `ARDUINOJSON_DOUBLE_IS_64BITS` as it became useless.
* Fixed too many decimals places in float serialization (issue #543)

v5.11.0
-------

* Made `JsonBuffer` non-copyable (PR #524 by @luisrayas3)
* Added `StaticJsonBuffer::clear()`
* Added `DynamicJsonBuffer::clear()`

v5.10.1
-------

* Fixed IntelliSense errors in Visual Micro (issue #483)
* Fixed compilation in IAR Embedded Workbench (issue #515)
* Fixed reading "true" as a float (issue #516)
* Added `ARDUINOJSON_DOUBLE_IS_64BITS`
* Added `ARDUINOJSON_EMBEDDED_MODE`

v5.10.0
-------

* Removed configurable number of decimal places (issues #288, #427 and #506)
* Changed exponentiation thresholds to `1e7` and `1e-5` (issues #288, #427 and #506)
* `JsonVariant::is<double>()` now returns `true` for integers
* Fixed error `IsBaseOf is not a member of ArduinoJson::TypeTraits` (issue #495)
* Fixed error `forming reference to reference` (issue #495)

> ### BREAKING CHANGES :warning:
>
> | Old syntax                      | New syntax          |
> |:--------------------------------|:--------------------|
> | `double_with_n_digits(3.14, 2)` | `3.14`              |
> | `float_with_n_digits(3.14, 2)`  | `3.14f`             |
> | `obj.set("key", 3.14, 2)`       | `obj["key"] = 3.14` |
> | `arr.add(3.14, 2)`              | `arr.add(3.14)`     |
>
> | Input     | Old output | New output |
> |:----------|:-----------|:-----------|
> | `3.14159` | `3.14`     | `3.14159`  |
> | `42.0`    | `42.00`    | `42`       |
> | `0.0`     | `0.00`     | `0`        |
>
> | Expression                     | Old result | New result |
> |:-------------------------------|:-----------|:-----------|
> | `JsonVariant(42).is<int>()`    | `true`     | `true`     |
> | `JsonVariant(42).is<float>()`  | `false`    | `true`     |
> | `JsonVariant(42).is<double>()` | `false`    | `true`     |

v5.9.0
------

* Added `JsonArray::remove(iterator)` (issue #479)
* Added `JsonObject::remove(iterator)`
* Renamed `JsonArray::removeAt(size_t)` into `remove(size_t)`
* Renamed folder `include/` to `src/`
* Fixed warnings `floating constant exceeds range of float`and `floating constant truncated to zero` (issue #483)
* Removed `Print` class and converted `printTo()` to a template method (issue #276)
* Removed example `IndentedPrintExample.ino`
* Now compatible with Particle 0.6.1, thanks to Jacob Nite (issue #294 and PR #461 by @foodbag)

v5.8.4
------

* Added custom implementation of `strtod()` (issue #453)
* Added custom implementation of `strtol()` (issue #465)
* `char` is now treated as an integral type (issue #337, #370)

v5.8.3
------

* Fixed an access violation in `DynamicJsonBuffer` when memory allocation fails (issue #433)
* Added operators `==` and `!=` for two `JsonVariant`s (issue #436)
* Fixed `JsonVariant::operator[const FlashStringHelper*]` (issue #441)

v5.8.2
------

* Fixed parsing of comments (issue #421)
* Fixed ignored `Stream` timeout (issue #422)
* Made sure we don't read more that necessary (issue #422)
* Fixed error when the key of a `JsonObject` is a `char[]` (issue #423)
* Reduced code size when using `const` references
* Fixed error with string of type `unsigned char*` (issue #428)
* Added `deprecated` attribute on `asArray()`, `asObject()` and `asString()` (issue #420)

v5.8.1
------

* Fixed error when assigning a `volatile int` to a `JsonVariant` (issue #415)
* Fixed errors with Variable Length Arrays (issue #416)
* Fixed error when both `ARDUINOJSON_ENABLE_STD_STREAM` and `ARDUINOJSON_ENABLE_ARDUINO_STREAM` are set to `1`
* Fixed error "Stream does not name a type" (issue #412)

v5.8.0
------

* Added operator `==` to compare `JsonVariant` and strings (issue #402)
* Added support for `Stream` (issue #300)
* Reduced memory consumption by not duplicating spaces and comments

> ### BREAKING CHANGES :warning:
>
> `JsonBuffer::parseObject()` and  `JsonBuffer::parseArray()` have been pulled down to the derived classes `DynamicJsonBuffer` and `StaticJsonBufferBase`.
>
> This means that if you have code like:
>
> ```c++
> void myFunction(JsonBuffer& jsonBuffer);
> ```
>
> you need to replace it with one of the following:
>
> ```c++
> void myFunction(DynamicJsonBuffer& jsonBuffer);
> void myFunction(StaticJsonBufferBase& jsonBuffer);
> template<typename TJsonBuffer> void myFunction(TJsonBuffer& jsonBuffer);
> ```

v5.7.3
------

* Added an `printTo(char[N])` and `prettyPrintTo(char[N])` (issue #292)
* Added ability to set a nested value like this: `root["A"]["B"] = "C"` (issue #352)
* Renamed `*.ipp` to `*Impl.hpp` because they were ignored by Arduino IDE (issue #396)

v5.7.2
------

* Made PROGMEM available on more platforms (issue #381)
* Fixed PROGMEM causing an exception on ESP8266 (issue #383)

v5.7.1
------

* Added support for PROGMEM (issue #76)
* Fixed compilation error when index is not an `int` (issue #381)

v5.7.0
------

* Templatized all functions using `String` or `std::string`
* Removed `ArduinoJson::String`
* Removed `JsonVariant::defaultValue<T>()`
* Removed non-template `JsonObject::get()` and `JsonArray.get()`
* Fixed support for `StringSumHelper` (issue #184)
* Replaced `ARDUINOJSON_USE_ARDUINO_STRING` by `ARDUINOJSON_ENABLE_STD_STRING` and `ARDUINOJSON_ENABLE_ARDUINO_STRING` (issue #378)
* Added example `StringExample.ino` to show where `String` can be used
* Increased default nesting limit to 50 when compiled for a computer (issue #349)

> ### BREAKING CHANGES :warning:
>
> The non-template functions `JsonObject::get()` and `JsonArray.get()` have been removed. This means that you need to explicitely tell the type you expect in return.
>
> Old code:
>
> ```c++
> #define ARDUINOJSON_USE_ARDUINO_STRING 0
> JsonVariant value1 = myObject.get("myKey");
> JsonVariant value2 = myArray.get(0);
> ```
>
> New code:
>
> ```c++
> #define ARDUINOJSON_ENABLE_ARDUINO_STRING 0
> #define ARDUINOJSON_ENABLE_STD_STRING 1
> JsonVariant value1 = myObject.get<JsonVariant>("myKey");
> JsonVariant value2 = myArray.get<JsonVariant>(0);
> ```

v5.6.7
------

* Fixed `array[idx].as<JsonVariant>()` and `object[key].as<JsonVariant>()`
* Fixed return value of `JsonObject::set()` (issue #350)
* Fixed undefined behavior in `Prettyfier` and `Print` (issue #354)
* Fixed parser that incorrectly rejected floats containing a `+` (issue #349)

v5.6.6
------

* Fixed `-Wparentheses` warning introduced in v5.6.5 (PR #335 by @nuket)
* Added `.mbedignore` for ARM mbdeb (PR #334 by @nuket)
* Fixed  `JsonVariant::success()` which didn't propagate `JsonArray::success()` nor `JsonObject::success()` (issue #342).

v5.6.5
------

* `as<char*>()` now returns `true` when input is `null` (issue #330)

v5.6.4
------

* Fixed error in float serialization (issue #324)

v5.6.3
------

* Improved speed of float serialization (about twice faster)
* Added `as<JsonArray>()` as a synonym for `as<JsonArray&>()`... (issue #291)
* Fixed `call of overloaded isinf(double&) is ambiguous` (issue #284)

v5.6.2
------

* Fixed build when another lib does `#undef isnan` (issue #284)

v5.6.1
------

* Added missing `#pragma once` (issue #310)

v5.6.0
------

* ArduinoJson is now a header-only library (issue #199)

v5.5.1
------

* Fixed compilation error with Intel Galileo (issue #299)

v5.5.0
------

* Added `JsonVariant::success()` (issue #279)
* Renamed `JsonVariant::invalid<T>()` to `JsonVariant::defaultValue<T>()`

v5.4.0
------

* Changed `::String` to `ArduinoJson::String` (issue #275)
* Changed `::Print` to `ArduinoJson::Print` too

v5.3.0
------

* Added custom implementation of `ftoa` (issues #266, #267, #269 and #270)
* Added `JsonVariant JsonBuffer::parse()` (issue #265)
* Fixed `unsigned long` printed as `signed long` (issue #170)

v5.2.0
------

* Added `JsonVariant::as<char*>()` as a synonym for `JsonVariant::as<const char*>()` (issue #257)
* Added example `JsonHttpClient` (issue #256)
* Added `JsonArray::copyTo()` and `JsonArray::copyFrom()` (issue #254)
* Added `RawJson()` to insert pregenerated JSON portions (issue #259)

v5.1.1
------

* Removed `String` duplication when one replaces a value in a `JsonObject` (PR #232 by @ulion)

v5.1.0
------

* Added support of `long long` (issue #171)
* Moved all build settings to `ArduinoJson/Configuration.hpp`

> ### BREAKING CHANGE :warning:
>
> If you defined `ARDUINOJSON_ENABLE_STD_STREAM`, you now need to define it to `1`.

v5.0.8
------

* Made the library compatible with [PlatformIO](http://platformio.org/) (issue #181)
* Fixed `JsonVariant::is<bool>()` that was incorrectly returning false (issue #214)

v5.0.7
------

* Made library easier to use from a CMake project: simply `add_subdirectory(ArduinoJson/src)`
* Changed `String` to be a `typedef` of `std::string` (issues #142 and #161)

> ### BREAKING CHANGES :warning:
>
> - `JsonVariant(true).as<String>()` now returns `"true"` instead of `"1"`
> - `JsonVariant(false).as<String>()` now returns `"false"` instead of `"0"`

v5.0.6
------

* Added parameter to `DynamicJsonBuffer` constructor to set initial size (issue #152)
* Fixed warning about library category in Arduino 1.6.6 (issue #147)
* Examples: Added a loop to wait for serial port to be ready (issue #156)

v5.0.5
------

* Added overload `JsonObjectSuscript::set(value, decimals)` (issue #143)
* Use `float` instead of `double` to reduce the size of `JsonVariant` (issue #134)

v5.0.4
------

* Fixed ambiguous overload with `JsonArraySubscript` and `JsonObjectSubscript` (issue #122)

v5.0.3
------

* Fixed `printTo(String)` which wrote numbers instead of strings (issue #120)
* Fixed return type of `JsonArray::is<T>()` and some others (issue #121)

v5.0.2
------

* Fixed segmentation fault in `parseObject(String)` and `parseArray(String)`, when the
  `StaticJsonBuffer` is too small to hold a copy of the string
* Fixed Clang warning "register specifier is deprecated" (issue #102)
* Fixed GCC warning "declaration shadows a member" (issue #103)
* Fixed memory alignment, which made ESP8266 crash (issue #104)
* Fixed compilation on Visual Studio 2010 and 2012 (issue #107)

v5.0.1
------

* Fixed compilation with Arduino 1.0.6 (issue #99)

v5.0.0
------

* Added support of `String` class (issues #55, #56, #70, #77)
* Added `JsonBuffer::strdup()` to make a copy of a string (issues #10, #57)
* Implicitly call `strdup()` for `String` but not for `char*` (issues #84, #87)
* Added support of non standard JSON input (issue #44)
* Added support of comments in JSON input (issue #88)
* Added implicit cast between numerical types (issues #64, #69, #93)
* Added ability to read number values as string (issue #90)
* Redesigned `JsonVariant` to leverage converting constructors instead of assignment operators (issue #66)
* Switched to new the library layout (requires Arduino 1.0.6 or above)

> ### BREAKING CHANGES :warning:
>
> - `JsonObject::add()` was renamed to `set()`
> - `JsonArray::at()` and `JsonObject::at()` were renamed to `get()`
> - Number of digits of floating point value are now set with `double_with_n_digits()`

**Personal note about the `String` class**:
Support of the `String` class has been added to the library because many people use it in their programs.
However, you should not see this as an invitation to use the `String` class.
The `String` class is **bad** because it uses dynamic memory allocation.
Compared to static allocation, it compiles to a bigger, slower program, and is less predictable.
You certainly don't want that in an embedded environment!

v4.6
----

* Fixed segmentation fault in `DynamicJsonBuffer` when memory allocation fails (issue #92)

v4.5
----

* Fixed buffer overflow when input contains a backslash followed by a terminator (issue #81)

**Upgrading is recommended** since previous versions contain a potential security risk.

Special thanks to [Giancarlo Canales Barreto](https://github.com/gcanalesb) for finding this nasty bug.

v4.4
----

* Added `JsonArray::measureLength()` and `JsonObject::measureLength()` (issue #75)

v4.3
----

* Added `JsonArray::removeAt()` to remove an element of an array (issue #58)
* Fixed stack-overflow in `DynamicJsonBuffer` when parsing huge JSON files (issue #65)
* Fixed wrong return value of `parseArray()` and `parseObject()` when allocation fails (issue #68)

v4.2
----

* Switched back to old library layout (issues #39, #43 and #45)
* Removed global new operator overload (issue #40, #45 and #46)
* Added an example with EthernetServer

v4.1
----

* Added DynamicJsonBuffer (issue #19)

v4.0
----

* Unified parser and generator API (issue #23)
* Updated library layout, now requires Arduino 1.0.6 or newer

> ### BREAKING CHANGES :warning:
>
> API changed significantly since v3, see [Migrating code to the new API](https://arduinojson.org/doc/migration/).

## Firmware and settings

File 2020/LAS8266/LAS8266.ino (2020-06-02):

// HEADERS
#include <ESP8266WiFi.h>
#include <ESP8266HTTPClient.h>
#include <ArduinoOTA.h>
#include <FS.h>

// EXTERNAL LIBRARIES
#include <ESPAsyncTCP.h>
#include <ESPAsyncWebServer.h>
#include <PubSubClient.h>
#include <uMQTTBroker.h>
#include <ArduinoJson.h>

// INTERNAL LIBRARIES
#include "HAS8266.h"
#include "HLW8012.h"

// VARIABLES
HAS8266 has8266;
HLW8012 hlw8012;
AsyncWebServer server(80); // WEB SERVER ON PORT 8080

// COUNTERS
byte SEND_HELLO = false;
byte SEND_POWER = false;
byte POWER = 3;

// GATEWAY
DynamicJsonDocument devices(4096);

// MQTT GATEWAY ON PORT 1883
class MQTTBroker: public uMQTTBroker 
{
  // ON CONNECT
  public: virtual bool onConnect(IPAddress addr, uint16_t client_count) 
  {
    // IP
    String ip = addr.toString();
    Serial.println("Connected MQTT Client IP: " + ip);

    // JSON
    JsonObject object;
    if (devices.containsKey(ip)) object = devices[ip];
    else object = devices.createNestedObject(ip);

    // 1. HELLO
    String msg_hello = "{\"from\":\""+WiFi.softAPIP().toString()+"\",\"to\":\""+ip+"\",\"name\":\""+has8266.getName()+"\"}";
    this->publish("hello", msg_hello);

    return true;
  }

  // ON DATA RECEIVED
  virtual void onData(String mqtt_topic, const char * mqtt_payload, uint32_t length) 
  {
    // Log
    StaticJsonDocument<1024> payload;
    DeserializationError error = deserializeJson(payload, mqtt_payload);
    if (error) return;
    
    // STOP SELF SENDING
    String ip_from = payload["from"];   
    String ip_to = payload["to"];  
    if(ip_to != WiFi.softAPIP().toString()) return;

    // DEBUG
    String msg;
    serializeJson(payload, msg);
    Serial.println("MQTT [" + mqtt_topic + "]: " + msg);

    // HELLO
    if (mqtt_topic == "hello") 
    {
      JsonObject object;
      if (devices.containsKey(ip_from)) object = devices[ip_from];
      else object = devices.createNestedObject(ip_from);

      object["name"] = payload["name"];
      object["power"] = 0; // W
      object["current"] = 0; // A
      object["voltage"] = 0; // V

      // STOP
      String msg_stop = "{\"from\":\"" + WiFi.softAPIP().toString() + "\",\"to\":\"" + ip_from + "\"}";
      this->publish("stop", msg_stop);
    }

    // POWER
    if (mqtt_topic == "power") 
    {
      JsonObject object = devices[ip_from];
      object["power"] = payload["power"]; // W
      object["current"] = payload["current"]; // A
      object["voltage"] = payload["voltage"]; // V

      // STOP
      if(POWER <= 0)
      {
        String msg_stop = "{\"from\":\"" + WiFi.softAPIP().toString() + "\",\"to\":\"" + ip_from + "\"}";
        this->publish("stop", msg_stop);
        POWER = 3;
      } else POWER--;
    }
  }

  // POST
  virtual void post(String mqtt_topic, String mqtt_payload) 
  {
     Serial.println("MQTT [" + mqtt_topic + "]: " + mqtt_payload );
     this->publish(mqtt_topic, mqtt_payload.c_str());
  }
};
MQTTBroker gw_mqtt;

// MQTT HOST ON PORT 1883
WiFiClient hs_wifi;
PubSubClient hs_mqtt(hs_wifi); 

// MQTT CALLBACK
void hs_mqtt_callback(char * mqtt_topic, uint8_t * mqtt_payload, unsigned int mqtt_length) 
{
  // Message: Topic and Paylod
  String topic(mqtt_topic), payload = (char*)mqtt_payload;
  payload = payload.substring(0, mqtt_length);

  //  Log
  DynamicJsonDocument json(1024);
  DeserializationError error = deserializeJson(json, payload);
  if (error) return;

  // STOP SELF SENDING

  String ip_from = json["from"];   
  String ip_to = json["to"];  
  if(ip_to != WiFi.localIP().toString()) return;
  Serial.println("MQTT [" + topic + "]: " + payload);

  // HELLO
  if (topic == "hello") 
  {
    SEND_HELLO = true;
    SEND_POWER = false;
  }
  
  // STOP
  if (topic == "stop") 
  {    
    SEND_HELLO = false;
    SEND_POWER = false;
  }

  // CONTROL
  if (topic == "control") 
  {
    String relay = json["relay"];
    if (relay == "1") digitalWrite(RELAY_PIN, RELAY_ON);
    else digitalWrite(RELAY_PIN, RELAY_OFF);
    SEND_HELLO = false;
    SEND_POWER = true;
  }
}

// HOST MQTT RECONNECT
void hs_mqtt_reconnect() 
{
  while (!hs_mqtt.connected()) 
  {
    if (hs_mqtt.connect(has8266.getName().c_str())) 
    {
      hs_mqtt.subscribe("hello");
      hs_mqtt.subscribe("control");
      hs_mqtt.subscribe("stop");
      SEND_HELLO = true;
      SEND_POWER = false;
      return;
    } 
    else delay(250);
  }
}

// WEB [SETUP]
void onSetupPost(AsyncWebServerRequest * request) 
{
  // ACCESS POINT MODE
  if (has8266.getMode() == AccessPoint) 
  {
    // SPIFFS
    SPIFFS.begin();

    // INI
    File file1 = SPIFFS.open("/NAME", "w");
    file1.print(request->arg("name"));
    file1.close();

    File file2 = SPIFFS.open("/MODE", "w");
    file2.print(request->arg("mode"));
    file2.close();

    // RESTART
    SPIFFS.end();
    delay(2000);
    ESP.restart();
  }
  // HOST MODE
  else request->send(SPIFFS, "/404.html");
}
// WEB [DEVICES] GET
void onDevicesGet(AsyncWebServerRequest * request) 
{
  // Async Json Response Stream ( MAX = 4KB )
  AsyncResponseStream * response = request->beginResponseStream("text/json");
  response->addHeader("Access-Control-Allow-Origin", "*");
  String json;
  serializeJson(devices, json);
  response->print(json);
  request->send(response);
}
// WEB [DEVICES] POST
void onDevicesPost(AsyncWebServerRequest * request) 
{
  DynamicJsonDocument json(1024);
  DeserializationError error = deserializeJson(json, request->arg("devices"));
  if (error) request->send(200, "text/plain", "MQTT [ERROR]");
  String payload;
  serializeJson(json, payload); 
  gw_mqtt.post("control", payload); 
  request->send(200, "text/plain", "MQTT [OK]");
}
// PAGE NOT FOUND
void on404(AsyncWebServerRequest * request) 
{
  request->send(SPIFFS, "/404.html");
}

// SOFTWARE RESET
void ICACHE_RAM_ATTR software_reset() 
{
  SPIFFS.begin();
  SPIFFS.remove("/NAME");
  SPIFFS.remove("/MODE");
  SPIFFS.end();
  delay(2000);
  ESP.restart();
}

// HLW8012
// When using interrupts we have to call the library entry point whenever an interrupt is triggered
void ICACHE_RAM_ATTR hlw8012_cf1_interrupt() {
  hlw8012.cf1_interrupt();
}
void ICACHE_RAM_ATTR hlw8012_cf_interrupt() {
  hlw8012.cf_interrupt();
}

// SETUP
void setup() 
{
  // DEBUG
  Serial.begin(115200);
  Serial.println("\n\n");

  // LED (GPIO14)
  pinMode(STATUS_PIN, OUTPUT);
  digitalWrite(STATUS_PIN, STATUS_OFF);
  // RELAY (GPIO10)
  pinMode(RELAY_PIN, OUTPUT);
  digitalWrite(RELAY_PIN, RELAY_OFF);
  // CF (GPIO13)
  pinMode(CF_PIN, INPUT_PULLUP);
  // CF1 (GPIO12)
  pinMode(CF1_PIN, INPUT_PULLUP);
  // SEL (GPIO16)
  pinMode(SEL_PIN, OUTPUT);
  digitalWrite(SEL_PIN, LOW);

  // SOFTWARE RESET
  pinMode(RESET_PIN, INPUT);
  attachInterrupt(digitalPinToInterrupt(RESET_PIN), software_reset, FALLING);

  // SPIFFS
  if (!SPIFFS.begin()) 
  {
    SPIFFS.format();
    delay(5000);
    ESP.restart();
  }

  // ACCESS POINT MODE
  if (!SPIFFS.exists("/NAME") || !SPIFFS.exists("/MODE")) 
  {
    // MODE
    has8266.setMode("AP");
    WiFi.mode(WIFI_AP);
    WiFi.softAP("HAS8266");

    // DEBUG
    // WiFi.printDiag(Serial);
    Serial.print("Access Point IP Address: ");
    Serial.println(WiFi.softAPIP());

    // WEB SERVER
    server.serveStatic("/", SPIFFS, "/").setDefaultFile("setup.html");
    server.on("/setup.html", HTTP_POST, onSetupPost);
    server.onNotFound(on404);
    server.begin();
  }

  // SETTINGS
  else 
  {
    // NAME
    File file1 = SPIFFS.open("/NAME", "r");
    String buffer1 = "";
    while (file1.available()) buffer1 += file1.readString();
    file1.close();
    has8266.setName(buffer1);
    Serial.println("DEVICE: " + buffer1);

    // MODE
    File file2 = SPIFFS.open("/MODE", "r");
    String buffer2 = "";
    while (file2.available()) buffer2 += file2.readString();
    file2.close();
    has8266.setMode(buffer2);
    Serial.println("MODE: " + buffer2);
    Serial.println();
  }

  // GATEWAY
  if (has8266.getMode() == GateWay) 
  {
    // MODE    
    // WiFi.mode(WIFI_AP_STA);
    WiFi.mode(WIFI_AP);
    WiFi.softAP("HAS8266");
   
    // DEBUG
    WiFi.printDiag(Serial);
    Serial.print("GateWay IP address: ");
    Serial.println(WiFi.softAPIP());

    // MQTT
    gw_mqtt.init();
    gw_mqtt.subscribe("hello");
    gw_mqtt.subscribe("power");

    // WEB SERVER
    server.serveStatic("/", SPIFFS, "/").setDefaultFile("devices.html").setCacheControl("max-age=3600");
    server.on("/devices.json", HTTP_GET, onDevicesGet);
    server.on("/devices.json", HTTP_POST, onDevicesPost);
    server.onNotFound(on404);
    server.begin();
  }

  // HOST
  if (has8266.getMode() == Host) 
  {
    // MODE
    WiFi.mode(WIFI_STA);
    WiFi.begin("HAS8266");
    while (WiFi.status() != WL_CONNECTED) delay(1000);

    // DEBUG
    WiFi.printDiag(Serial);
    Serial.print("Host IP address: ");
    Serial.println(WiFi.localIP());

    // MQTT
    byte gw_mqtt_server[] = { 192, 168, 4, 1 };
    hs_mqtt.setServer(gw_mqtt_server, 1883);
    hs_mqtt.setCallback(hs_mqtt_callback);
    hs_mqtt_reconnect();

    /* // HLW8012
     * CF_PIN, CF1_PIN and SEL_PIN are GPIOs to the HLW8012 IC.
     * CURRENT_MODE uses SEL_PIN to select current sampling.
     * Set USE_INTERRUPTS to TRUE to use interrupts to monitor pulse widths.
     * Leave PULSE_TIMEOUT to the default value, recommended when using interrupts. */
    hlw8012.begin(CF_PIN, CF1_PIN, SEL_PIN, CURRENT_MODE, true);
    /* // RESISTORS
     * These values are used to calculate current, voltage and power factors as per datasheet
     * formula.
     * These are the nominal values for the Sonoff POW resistors:
     * - The CURRENT_RESISTOR is the 1 milli Ohm copper-manganese resistor in series with the
     * main line.
     * - The VOLTAGE_RESISTOR_UPSTREAM are the 5470 kOhm resistors in the voltage divider that
     * feeds the V2P pin in the HLW8012.
     * - The VOLTAGE_RESISTOR_DOWNSTREAM is the 1 kOhm resistor in the voltage divider that
     * feeds the V2P pin in the HLW8012. */
    hlw8012.setResistors(CURRENT_RESISTOR, VOLTAGE_RESISTOR_UPSTREAM, VOLTAGE_RESISTOR_DOWNSTREAM);
    // INTERRUPTS
    attachInterrupt(CF1_PIN, hlw8012_cf1_interrupt, FALLING);
    attachInterrupt(CF_PIN, hlw8012_cf_interrupt, FALLING);
  }

  // OTA UPDATES
  ArduinoOTA.setPort(8266);
  ArduinoOTA.begin();
}

// LOOP
void loop() 
{
  // HEARTBEAT
  digitalWrite(STATUS_PIN, STATUS_ON);
  
  // OTA 
  ArduinoOTA.handle();

  // HOST
  if (has8266.getMode() == Host) 
  {
    // MQTT
    if (!hs_mqtt.connected()) hs_mqtt_reconnect();
    hs_mqtt.loop();

    // HELLO
    if (SEND_HELLO) 
    {
      String hello = "{\"from\":\"" + WiFi.localIP().toString() + "\",\"to\":\"192.168.4.1\",\"name\":\"" + has8266.getName() + "\"}";     
      hs_mqtt.publish("hello", hello.c_str());
    }

    // POWER
    if (SEND_POWER) 
    {
      String payload = "";
      DynamicJsonDocument doc(1024);
      doc["from"] = WiFi.localIP().toString();
      doc["to"] = "192.168.4.1";
      doc["power"] = 0; // W
      doc["current"] = 0; // A
      doc["voltage"] = 0; // V
      if(digitalRead(RELAY_PIN) == RELAY_ON)
      {
        delay(1000); 
        doc["power"] = hlw8012.getActivePower(); // W
        doc["current"] = hlw8012.getCurrent(); // A
        doc["voltage"] = hlw8012.getVoltage(); // V
      }
      serializeJson(doc, payload);
      hs_mqtt.publish("power", payload.c_str());
    }
  }

  // WDT RESET
  delay(250);
  digitalWrite(STATUS_PIN, STATUS_OFF);
  delay(250);
}

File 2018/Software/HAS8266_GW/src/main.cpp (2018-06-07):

#include <Arduino.h>

// TCP/IP Fixes
extern "C" {
// Headers
#include "lwip/ip.h"
#include "lwip/tcp.h"
#include "lwip/tcp_impl.h"
#include "user_interface.h"
// TCP/IP Max Socket Client Connections
uint8 espconn_tcp_get_max_con(void);
sint8 espconn_tcp_set_max_con(uint8 num);
void tcpFixes() 
{
  uint8 maxtcp = espconn_tcp_get_max_con();
  sint8 maxtcpfix = espconn_tcp_set_max_con(15);
  // Turn Off ESP8266 Sleep Mode
  wifi_set_sleep_type(NONE_SLEEP_T);
}
// TCP/IP Connections Cleanup
void tcpCleanup() 
{ 
  while(tcp_tw_pcbs!=NULL) tcp_abort(tcp_tw_pcbs); 
}
};

// Headers
#include <WiFiClient.h>
#include <WiFiUdp.h>
#include <ArduinoOTA.h>
#include <ESP8266WiFi.h>
#include <ESP8266mDNS.h>
#include <ESP8266HTTPClient.h>

// Libraries
#include <ESPAsyncTCP.h>
#include <ESPAsyncWebServer.h>
#include <PubSubClient.h>
#include <ArduinoJson.h>
#include <AsyncJson.h>
#include <Ticker.h>
#include <ESP8266Ping.h>

// My Libraries
#include <HAS8266.h>
#include <IniFile.h>
#include <MQTTbroker.h>
#include <Telnet.h>
#include <NTPClient.h>

// Variables
HAS8266 has8266;
MQTTbroker mqtt;           // MQTT on port 1883
Telnet telnet;             // Telnet on port 23
AsyncWebServer server(80); // Web Server on port 8080
AsyncWebServer ota(8266);  // OTA Updates on port 8266
WiFiUDP udp;
NTPClient ntp(udp);        // NTP on port 1337

// JSON (Devices & History)
DynamicJsonBuffer jsonBuffer(1024);
// DynamicJsonBuffer jsonBuffer;
JsonObject &devices = jsonBuffer.createObject();
JsonObject &history = jsonBuffer.createObject();

// RESET
void software_reset()
{
    telnet.print("HAS8266 [RESET]");
    SPIFFS.begin();
    SPIFFS.remove("/setup.ini");
    SPIFFS.end();
    delayMicroseconds(2000); // delay(2000);
    ESP.restart();
}

// WIFI
void wifi_connect()
{
    // Access Point Mode
    if (has8266.getDeviceMode() == AccessPoint)
    {
        char _ssid[sizeof(has8266.getSsid()) + 1];
        has8266.getSsid().toCharArray(_ssid, sizeof(_ssid));
        WiFi.mode(WIFI_AP); // WIFI_AP or WIFI_STA
        WiFi.softAP(_ssid);
        delayMicroseconds(2000); // delay(2000);  
        telnet.print("WIFI [ACCESS POINT MODE]");
        telnet.print("ACCESS POINT IP ADDRESS = " + WiFi.softAPIP().toString());     
    }

    // Host Mode
    if (has8266.getDeviceMode() == GateWay)
    {
        telnet.print("INI [LOAD]");
        IniFile Setup(SPIFFS, "/setup.ini");
        const size_t bufferLen = 80;
        char buffer[bufferLen];

        // INI file: [Section] Name = Value
        if (Setup.getValue("setup", "ssid", buffer, bufferLen)) has8266.setSsid((String)buffer);
        if (Setup.getValue("setup", "pass", buffer, bufferLen)) has8266.setPass((String)buffer);

        telnet.print("WIFI [GATEWAY MODE]");
        telnet.print("SSID: " + has8266.getSsid());
        telnet.print("PASS: " + has8266.getPass());
        telnet.print("WIFI [CONNECT] ");

        // WIFI
        char _ssid[sizeof(has8266.getSsid()) + 1], _pass[sizeof(has8266.getPass()) + 1];
        has8266.getSsid().toCharArray(_ssid, sizeof(_ssid));
        has8266.getPass().toCharArray(_pass, sizeof(_pass));
        WiFi.mode(WIFI_STA); // WIFI_AP or WIFI_STA
        WiFi.begin(_ssid, _pass);
        while (WiFi.status() != WL_CONNECTED) delay(1000);

        telnet.print("GATEWAY IP ADDRESS = " + WiFi.localIP().toString());
    }

    // TCP/IP Fixes
    tcpFixes();
}

// MQTT
void mqtt_callback(IPAddress mqtt_ip, String mqtt_topic, uint8_t *mqtt_payload, uint8_t mqtt_length)
{
    // Disable WDT
    // wdt_disable();

    // LED ON
    digitalWrite(STATUS_PIN, STATUS_ON);

    // IP Address
    String ip = String(mqtt_ip[0]) + String(".") + String(mqtt_ip[1]) + String(".") + String(mqtt_ip[2]) + String(".") + String(mqtt_ip[3]);

    // Log
    JsonObject &payload = jsonBuffer.parseObject(mqtt_payload);
    if (payload.success())
    {
        String msg;
        payload.printTo(msg);
        telnet.print("MQTT [RECEIVE] #" + ip + " [" + mqtt_topic + "] " + msg);
    }
    else
    {
        digitalWrite(STATUS_PIN, STATUS_OFF);
        return;
    }

    // Message Hello
    if (mqtt_topic == "hello")
    {
        JsonObject &object = devices.containsKey(ip) ? devices[ip] : devices.createNestedObject(ip);
        object.set("name", payload["name"].as<String>());
        object.set("power", 0);   // W
        object.set("current", 0); // A
        object.set("voltage", 0); // V
        // Hello
        String hello = "{\"name\":\"" + has8266.getDevice() + "\"}";
        mqtt.publish(mqtt_ip, "hello", hello);
        // MQTT Total Connected Clients
        QList<String> _clients = mqtt.clients();
        telnet.print("MQTT Total Connected Clients = " + (String)_clients.size());
        while(_clients.size() > 0)
        {
           String IP = _clients.front();
           _clients.pop_front();
           telnet.print("#" + IP);
        }
    }

    // Message Power
    if (mqtt_topic == "power")
    {
        JsonObject &object = devices[ip];
        object.set("power", (float)payload["power"]);     // W
        object.set("current", (float)payload["current"]); // A
        object.set("voltage", (float)payload["voltage"]); // V
    }

    // LED OFF
    digitalWrite(STATUS_PIN, STATUS_OFF);

    // Enable WDT
    // wdt_enable();
}

// WEB [SETUP]
void onSetupPost(AsyncWebServerRequest *request)
{
    // Disable WDT
    wdt_disable();

    telnet.print("HTTP [SETUP]");

    // Access Point Mode
    if (has8266.getDeviceMode() == AccessPoint)
    {
        // INI
        File fileIni = SPIFFS.open("/setup.ini", "w+");
        if (!fileIni) telnet.print("INI [ERROR]");
        fileIni.print("[setup]\r\n");
        fileIni.print("ssid = " + request->arg("ssid") + "\r\n");
        fileIni.print("pass = " + request->arg("pass") + "\r\n");
        fileIni.close();
        telnet.print("INI [SAVE]");

        // RESTART
        telnet.print("HAS8266 [RESTART]");
        SPIFFS.end();
        delayMicroseconds(2000); // delay(2000);
        ESP.restart();
    }
    // Host Mode
    else request->send(SPIFFS, "/404.html");
}
// WEB [DEVICES] GET 
void onDevicesGet(AsyncWebServerRequest *request)
{
    telnet.print("HTTP [GET] DEVICES");
    // Async Json Response Stream ( MAX = 4KB )
    AsyncResponseStream *response = request->beginResponseStream("text/json");
    response->addHeader("Access-Control-Allow-Origin", "*");
    // devices.printTo(*response);
    devices.prettyPrintTo(*response);
    request->send(response);
}
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

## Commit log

2019-11-13 Version 1
    [HAS.sch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]
2021-04-08 Смяна на лиценза
